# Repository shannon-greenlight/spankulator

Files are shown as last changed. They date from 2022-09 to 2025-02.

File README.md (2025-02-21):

# Spankulator
# The Spankulator has been discontinued due to parts issues

The Spankulator is a WiFi-enabled multi-function Eurorack module. Its main function is to generate a trio of coordinated analog and digital signals which can be used in an endless variety of ways. While each output generates familiar signals, it is the coordination of these signals and the methods of control that make the Spankulator special.

# Spankulator-Hardware, Spankulator-Panel
These repos contain the materials needed to construct the Spankulator main board and the front panel.
The files are for KiCAD 6.0. Go to the Greenlight Kicad repo to get the needed libraries.
The gerber files work with JLCPC and will most likely work with other board manufacturers.
Assembly instructions are in spankulator_assembly.docx.

If starting from a bare circuit board, the BOM for the Spankulator is in bom/Digi-Key/spankulator_full.csv. This file can be directly uploaded to Digi-Key for buying parts.

If using the JLCPCB assembly service, the BOM is split into 3 parts.
- bom/LCSC/spankulator_bom.csv : The parts to be assembled by JLCPCB
- bom/Digi-Key/spankulator_split.csv : The remaining parts to be assembled by user
- bom/Other/other_bom.xlsx : The parts that must be bought from sources other than JLCPCB and Digi-Key

Also, when an assembly service is used, a component position file is required. This file's path is: fab/spankulator_cpl.xlsx

notes: 	The bom and cpl files are auto-generated from the csv BOM files produced by KiCAD. You will need to refresh the data when changes to the schematic that affect the BOM or changes to the board layout occur.
		The data that is the source of the BOM files is generated by the BOM function in KiCAD schematics. Use the bom2grouped_csv.xsl plugin that's supplied with KiCAD. 
		This produces Spankulator.xml, which is used by the Python scripts found in the KiCAD repository. https://github.com/shannon-greenlight/KiCAD
		Once Spankulator.xml is up to date, use the generate_boms.bat batch file to create the BOMs. Edit this file to set the directory locations to match your system.
		The cpl file source is generated by the KiCAD pcb Fabrication Output function. File->Fabrication Outputs->Component Placement. Make sure to select "Separate files for front and back".
		Select ./fab/pos as the output directory. This creates the pos files, the 'top' file being used as the data source for the cpl file that is sent to JLCPCB: fab/spankulator_cpl.xsl
		Make sure to refresh the data and save the file before sending it to JLCPCB.
		
The additional data fields that appear on the schematic help to produce the different BOM files. They must be maintained for these BOMs to come out right.

# Spankulator-Code
This repository contains the elements needed to build code for the Spankulator. 
The code is for the Arduino Nano 33 IoT and is found in the Spankulator folder. Make sure to get the required libraries from the Arduino-Libs repo.

The build files are for Windows. They are simple .bat files but depend on having a working Arduino development system.
Certain variables must be edited to adapt these files to a particular installation. 

Here is a list of the batch files and folders:
 
- make.bat ... compiles the code
- make_n_load.bat ... calls make.bat then uploads the code to the Spankulator
- load_recent.bat ... loads most recent compile
- list_ports.bat ... lists available COM ports
- release.bat ... used to update release number in the code and create release binary zip
- out ... this folder must be created. It holds compile output

# Du Dad
The Du Dad is an addition to the Spankulator that provides these benefits:

- Front Panel USB access
- Power sensing shuts off USB to Arduino when synth power is off
- Reset switch
- USB Power indicator
- Boot Loader / Ext Trig Disabled indicator
- Trig In Latch indicator
- Extremely useful to those who use Terminal Remote mode

The folder structure of the Du Dad is similar to the Spankulator Hardware folder. Currently there is no support for assembly service.

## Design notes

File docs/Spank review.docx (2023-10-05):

I'm the designer of the Spankulator. This is more of a description than a review.

The unit shown is new. Because Patchwerks needs to see some interest in my products before they carry them, I must sell in the consignment section. I'm hoping that people see how cool this module is and that this is a good way to get the ball rolling.

The Spankulator is designed to be a highly versatile coordinated Trigger/CV source.

Signals

Trig Out – Digital signal that consists of pulses of varying width.

Tog Out – Digital signal that toggles at the end of every sequence.

CV Out – Analog signal (+/- 5 volt) that depends on the Function. Usually, it is relative to the pulse width of the Trig Output. This signal is modified using the CV control.

Trigger In – Digital input. Operation is triggered with a 0 to 5 volt transition on this input. This also serves as the External Clock when Ext Clk mode is enabled.

Sig In – Analog signal input. Range: +/- 5 volt

Functions

5 Spank types – Up, Down, Stretch, Toggle and Maytag

LFO with 4 waveforms – Sine, Inv Sine, Ramp Up, Ramp Down

Bounce – A DVM plus a quantizable sample and hold. DC and AC modes

User Mode – For sending sequences of Spanks and/or LFO bursts

WiFi Mode – For configuring WiFi

Settings – For module configuration, factory reset, etc.

There is a lot more to say. I wrote a manual with 30 pages of useful info. You can find it here: https://www.greenfacelabs.com/wp-content/uploads/2023/08/Spankulator-Manual.pdf

If you are interested, please contact me directly using the contact page on my website. I'm constantly upgrading the Spankulator and will probably have some important updates.

And I'm looking for a Keith Emerson to help me make a name for Greenface Labs. If you have a significant following, or are an influencer and would like to check out the Spankulator for FREE please use the contact page to claim one for yourself. https://www.greenfacelabs.com/contact/ US or Canada only please.

Shannon Vance

Greenface Labs

Hood River, Oregon

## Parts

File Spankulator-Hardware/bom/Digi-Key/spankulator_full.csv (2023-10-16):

Reference | Quantity | Value | Digi-Key Part #
A1, | 1 | Nano_33IoT | 1050-ABX00032-ND
C1, C2, C18, C19, | 4 | 10nF | BC2662CT-ND
C3, C4, | 2 | 100uF | 10-ECE-A1CKA101ICT-ND
C5, C6, C7, C9, C12, C13, C17, C20, | 8 | 100nF | 399-9877-1-ND
C8, C10, C14, C21, | 4 | 1uF | 399-9886-1-ND
C11, C15, | 2 | 2.2uF | 478-12960-1-ND
C16, | 1 | 270p | 490-7362-1-ND
D1, D2, D7, D15, D16, D19, D20, | 7 | 1N5711 | 497-2499-1-ND
D3, | 1 | GREEN LED | 732-5008-ND
D4, | 1 | BLUE LED | 732-11401-ND
D5, | 1 | YELLOW LED | 160-1961-ND
D6, D13, | 2 | 1N4148 | 1N4148VSCT-ND
D8, | 1 | 1N5819 | 497-2499-1-ND
D9, | 1 | 1N5819 | 497-2499-1-ND
D14, | 1 | RED LED | 160-1035-ND
J1, J3, J4, J5, J6, | 5 | 3.5mm Jack | WM17366-ND
J2, J7, | 2 | 2x5 Header | S2011EC-05-ND
J9, | 1 | Display Header | SAM1011-04-ND
J11, | 1 | OLED Pins | 732-5317-ND
J12, J13, | 2 | Arduino Socket | S7048-ND
J14, | 1 | Eurorack Power Cable | H3CCS-1618G-ND
KN1, | 1 | Selector Knob | 226-4215-ND
KN2, | 1 | CV Knob | 1722-1314-ND
N2, N3, N4, N5, N6, N7, | 6 | Nut | 36-4687-ND
Q1, | 1 | 2N3904 | 2N3904FS-ND
R1, R5, R6, R11, R15, R22, | 6 | 10K | CF14JT10K0CT-ND
R2, R3, R4, R10, R14, | 5 | 1K | CF14JT1K00CT-ND
R7, R12, R24, R26, R27, R31, | 6 | 100K .1% | A105968CT-ND
R8, | 1 | 100K | 2019-CF1/4CT52R104JCT-ND
R9, R13, | 2 | 43K | CF14JT43K0CT-ND
R17, | 1 | 324K 1% | 324KXBK-ND
R18, | 1 | 68K | CF14JT68K0CT-ND
R19, R20, | 2 | 470 | PPC470W-1CT-ND
R23, R28, | 2 | 300K .1% | RN55E3003BB14-ND
R29, | 1 | 200K .1% | CMF200KHCCT-ND
R30, | 1 | 95.3K 1% | RNF14FTD95K3CT-ND
RV1, | 1 | 1K | PTV09A-4225F-B102-ND
RV2, RV3, | 2 | 20K | 490-2881-ND
SC2, SC4, SC6, SC8, | 4 | Nylon Screw | 36-29331-ND
SC3, SC5, SC7, SC9, | 4 | Mounting Screw | 335-1156-ND
SK1, SK2, SK3, SK5, | 4 | A_08-LC-TT | AE9986-ND
SK4, | 1 | A_14-LC-TT | AE9989-ND
SO2, SO3, SO5, SO7, | 4 | Standoff 12mm | 732-13063-ND
SO4, SO6, | 2 | Standoff 10mm | 732-13055-ND
SO8, SO9, SO10, SO11, SO12, | 5 | LED_Standoff | 732-11607-ND
SW1, | 1 | Adj | 987-1187-ND
SW2, SW3, SW4, SW5, SW6, SW7, SW8, | 7 | Push Button | 450-1643-ND
TP1, TP2, TP3, TP4, | 4 | TestPoint | 36-5006-ND
U1, U3, | 2 | TL072CP | 296-1775-5-ND
U2, | 1 | CD4013BE | 296-2033-5-ND
U4, | 1 | MC78L05_TO92 | 296-27135-1-ND
U5, | 1 | LP2950-3.3_TO92 | 296-26120-ND
U6, | 1 | MAX7480 | MAX7480EPA+-ND
U7, | 1 | MB85RC256 | 865-1261-1-ND
U8, | 1 | MCP6002-E/P | MCP6002-E/P-ND

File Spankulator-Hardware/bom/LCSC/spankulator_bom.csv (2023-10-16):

Designator | Comment | Footprint | JLCPCBPart#
C1, C2, C18, C19, | 10nF | Capacitor_THT:C_Disc_D4.3mm_W1.9mm_P5.00mm | C263180
C3, C4, | 100uF | Capacitor_THT:CP_Radial_D6.3mm_P2.50mm | C445356
C5, C6, C7, C9, C12, C13, C17, C20, | 100nF | Capacitor_THT:C_Disc_D4.3mm_W1.9mm_P5.00mm | C400087
C8, C10, C14, C21, | 1uF | Capacitor_THT:C_Disc_D4.3mm_W1.9mm_P5.00mm | C94708
C11, C15, | 2.2uF | sputterizer:CP_Radial_Tantal_D4.5mm_P5.00mm_Min | C50520
C16, | 270p | Capacitor_THT:C_Disc_D5.0mm_W2.5mm_P5.00mm | C263193
D1, D2, D7, D15, D16, D19, D20, | 1N5711 | Diode_THT:D_DO-35_SOD27_P7.62mm_Horizontal | C283247
D6, D13, | 1N4148 | Diode_THT:D_DO-35_SOD27_P7.62mm_Horizontal | C84412
D8, | 1N5819 | Diode_THT:D_DO-41_SOD81_P2.54mm_Vertical_AnodeUp | C110032
D9, | 1N5819 | Diode_THT:D_DO-41_SOD81_P2.54mm_Vertical_KathodeUp | C110032
Q1, | 2N3904 | Package_TO_SOT_THT:TO-92-3_Formed_Leads | C258185
R1, R5, R6, R11, R15, R22, | 10K | Resistor_THT:R_Axial_DIN0207_L6.3mm_D2.5mm_P10.16mm_Horizontal | C120103
R2, R3, R4, R10, R14, | 1K | Resistor_THT:R_Axial_DIN0207_L6.3mm_D2.5mm_P10.16mm_Horizontal | C66649
R7, R12, R24, R26, R27, R31, | 100K .1% | Resistor_THT:R_Axial_DIN0207_L6.3mm_D2.5mm_P10.16mm_Horizontal | C410694
R8, | 100K | Resistor_THT:R_Axial_DIN0207_L6.3mm_D2.5mm_P10.16mm_Horizontal | C120103
R9, R13, | 43K | Resistor_THT:R_Axial_DIN0207_L6.3mm_D2.5mm_P10.16mm_Horizontal | C433719
R17, | 324K 1% | Resistor_THT:R_Axial_DIN0207_L6.3mm_D2.5mm_P10.16mm_Horizontal | C1369146
R18, | 68K | Resistor_THT:R_Axial_DIN0207_L6.3mm_D2.5mm_P10.16mm_Horizontal | C70783
R19, R20, | 470 | Resistor_THT:R_Axial_DIN0207_L6.3mm_D2.5mm_P10.16mm_Horizontal | C129899
R23, R28, | 300K .1% | Resistor_THT:R_Axial_DIN0207_L6.3mm_D2.5mm_P10.16mm_Horizontal | C173001
R29, | 200K .1% | Resistor_THT:R_Axial_DIN0207_L6.3mm_D2.5mm_P10.16mm_Horizontal | C172982
R30, | 95.3K 1% | Resistor_THT:R_Axial_DIN0207_L6.3mm_D2.5mm_P10.16mm_Horizontal | C172602
SK1, SK2, SK3, SK5, | A_08-LC-TT | Package_DIP:DIP-8_W7.62mm_Socket | none
SK4, | A_14-LC-TT | digikey-footprints:Socket_DIP-14_7.62mm_Conn | none
SW2, SW3, SW4, SW5, SW6, SW7, SW8, | Push Button | Button_Switch_THT:SW_PUSH_6mm | C266209
U1, U3, | TL072CP | Package_DIP:DIP-8_W7.62mm_Socket | C72124
U2, | CD4013BE | Package_DIP:DIP-14_W7.62mm_Socket | C132508
U4, | MC78L05_TO92 | Package_TO_SOT_THT:TO-92_Inline_Wide | C156437
U5, | LP2950-3.3_TO92 | Package_TO_SOT_THT:TO-92-3_Formed_Leads | C133551
U6, | MAX7480 | Package_DIP:DIP-8_W7.62mm_Socket_LongPads | C72124
U7, | MB85RC256 | Package_SO:SOIC-8_3.9x4.9mm_P1.27mm | C47538
U8, | MCP6002-E/P | Package_DIP:DIP-8_W7.62mm_Socket | C72124

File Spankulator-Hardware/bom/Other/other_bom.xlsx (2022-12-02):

Reference | Quantity | Value | URL
A1 | 1 | Nano_33IoT | https://www.amazon.com/Arduino-Nano-33-IoT/dp/B07VW9TSKD/
M2 | 1 | OLED | https://www.amazon.com/gp/product/B072Q2X2LL/
RV2 | 1 | 20K | https://www.amazon.com/dp/B015RK03LI?psc=1&ref=ppx_yo2ov_dt_b_product_details

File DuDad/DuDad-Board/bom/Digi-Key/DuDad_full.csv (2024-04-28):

Reference | Quantity | Value | Digi-Key Part #
D1, | 1 | RED LED | 732-5005-ND
D2, | 1 | GREEN LED | 732-5008-ND
D3, | 1 | YELLOW LED | 732-5010-ND
J1, | 1 | EXP | S2011EC-05-ND
J2, | 1 | USB_B_Micro | 2073-USB3131-30-0230-ACT-ND
J3, | 1 | USB_A | UE27AE54100-ND
Q1, Q2, Q4, | 3 | 2N3906 | 2N3906TFCT-ND
Q3, | 1 | 2N7000 | 2N7000FS-ND
R1, R4, | 2 | 620 | CF14JT620RCT-ND
R2, R5, R7, R8, | 4 | 30K | CF14JT30K0CT-ND
R3, | 1 | 1K | CF14JT1K00CT-ND
R6, R9, | 2 | 10K | CF14JT10K0CT-ND
SW1, | 1 | Reset | 450-1653-ND

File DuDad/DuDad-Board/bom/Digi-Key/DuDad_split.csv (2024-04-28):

Reference | Quantity | Value | Digi-Key Part #
D1, | 1 | RED LED | 732-5005-ND
D2, | 1 | GREEN LED | 732-5008-ND
D3, | 1 | YELLOW LED | 732-5010-ND
J2, | 1 | USB_B_Micro | 2073-USB3131-30-0230-ACT-ND
SW1, | 1 | Reset | 450-1653-ND

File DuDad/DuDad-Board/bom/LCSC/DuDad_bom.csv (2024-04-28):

Designator | Comment | Footprint | JLCPCBPart#
J1, | EXP | Connector_PinHeader_2.54mm:PinHeader_2x05_P2.54mm_Vertical | C225520
J3, | USB_A | sputterizer:USB_A_Amphenol_UE27AE54100_Vertical | C386737
Q1, Q2, Q4, | 2N3906 | Package_TO_SOT_THT:TO-92_Inline_Wide | C9809
Q3, | 2N7000 | Package_TO_SOT_THT:TO-92_Inline_Wide | C232838
R1, R4, | 620 | Resistor_THT:R_Axial_DIN0207_L6.3mm_D2.5mm_P10.16mm_Horizontal | C120050
R2, R5, R7, R8, | 30K | Resistor_THT:R_Axial_DIN0207_L6.3mm_D2.5mm_P10.16mm_Horizontal | C176499
R3, | 1K | Resistor_THT:R_Axial_DIN0207_L6.3mm_D2.5mm_P10.16mm_Horizontal | C120055
R6, R9, | 10K | Resistor_THT:R_Axial_DIN0207_L6.3mm_D2.5mm_P10.16mm_Horizontal | C433778

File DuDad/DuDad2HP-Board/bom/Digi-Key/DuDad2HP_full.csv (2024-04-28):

Reference | Quantity | Value | Digi-Key Part #
D1, | 1 | RED LED | 732-5005-ND
D2, | 1 | GREEN LED | 732-5008-ND
D3, | 1 | YELLOW LED | 732-5010-ND
J1, | 1 | EXP | S2011EC-05-ND
J2, | 1 | USB_B_Micro | 2073-USB3131-30-0230-ACT-ND
J3, | 1 | USB_A | UE27AE54100-ND
Q1, Q2, Q4, | 3 | MMBT3906 | MMBT3906LT1GOSCT-ND
Q3, | 1 | 2N7002 | 2N7002LT1GOSCT-ND
R1, R4, | 2 | 620 | RMCF0805FT620RCT-ND
R2, R5, R7, R8, | 4 | 30K | RMCF0805FT30K0CT-ND
R3, | 1 | 1K | 311-1.00KCRCT-ND
R6, R9, | 2 | 10K | RMCF0805FT10K0CT-ND
SW1, | 1 | Reset | 450-1940-ND

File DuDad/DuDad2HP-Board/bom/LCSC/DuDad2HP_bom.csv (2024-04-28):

Designator | Comment | Footprint | JLCPCBPart#
J1, | EXP | Connector_PinHeader_2.54mm:PinHeader_2x05_P2.54mm_Vertical_SMD | C178296
J3, | USB_A | sputterizer:USB_A_Amphenol_UE27AE54100_Vertical | C386737
Q1, Q2, Q4, | MMBT3906 | Package_TO_SOT_SMD:SOT-23 | C266589
Q3, | 2N7002 | Package_TO_SOT_SMD:SOT-23 | C8545
R1, R4, | 620 | Resistor_SMD:R_0805_2012Metric_Pad1.20x1.40mm_HandSolder | C17782
R2, R5, R7, R8, | 30K | Resistor_SMD:R_0805_2012Metric_Pad1.20x1.40mm_HandSolder | C17621
R3, | 1K | Resistor_SMD:R_0805_2012Metric_Pad1.20x1.40mm_HandSolder | C17513
R6, R9, | 10K | Resistor_SMD:R_0805_2012Metric_Pad1.20x1.40mm_HandSolder | C17414

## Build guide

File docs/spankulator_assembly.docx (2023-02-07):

# Spankulator Assembly Instructions

The Spankulator uses components on both sides of the board. Pre-populated boards have most of the top side components installed. The order of assembly is designed to add components like the push buttons near the end of the process so they will not risk being damaged by the hot iron. However, pre-populated boards may have the buttons or other vulnerable components installed. In this case, extra caution is required.

These instructions work for bare boards and also for pre-populated boards from JLCPCB. In the latter case, you only will need to install components that haven’t already been installed. The list of these components can be found in the file: Spankulator-Hardware\bom\Digi-Key\ spankulator_split.csv

Because of the density of the circuitry, a conical .8mm tip soldering iron is suggested. It is strongly recommended that you read the Test Instructions before attempting assembly.

Difficulty: beginner. Not recommended for first two builds.

1. Load the Spankulator program onto the Arduino via micro-USB cable using the updater batch file. The latest updater package is found on the Spankulator page of the website. Other versions can be found in the Git repository.
2. Install 4 12mm stand-offs to the front panel using screws. Set this aside for later.
3. Install U7
4. Install all resistors, capacitors, diodes, transistors, test points, and sockets to the top side of the board.
5. Install ICs into sockets (not Arduino)
6. Install J9 display header to top side.
7. Install 2 10mm display stand-offs with nuts.
8. Solder header to Display board. Set this aside for later.
  a. Trim pins on top of display to insure proper fit onto the front panel.
  b. Note: the display is very fragile. Avoid unnecessary handling.
9. Install back side components. (Connectors, Arduino sockets, and trimpots)
10. Install display. Use wooden, round toothpicks to align display on standoffs. Insert toothpick from top and trim flush with display surface.
11. Loosely place the rest of the components (these should all be the ones that go through holes in the front panel) and attach front panel with the 4 nuts.
12. This should properly align all the front-panel components. Solder them in place.
13. Install Arduino on the back side of the board.
14. Attach knobs
15. That’s all! You’re ready to test.

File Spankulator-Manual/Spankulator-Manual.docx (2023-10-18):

# The Spankulator

User Manual

Greenface Labs -- 2023

# Quick Start

The Spankulator can be used in an endless variety of ways, but here is a great way to start exploring. These instructions are for use with a Moog Mother-32 but can be easily adapted to most modular synthesizers. Note - you may need to set the encoder type in Settings first.

#### Mother-32 Set-up

- VCA Mode – EG (use the envelope generator)
- VCO Mod Amount – Zero
- VCF Mode – Low Pass
- VCF Mod Source – EG
- VCF Mod Amount – 0%
- Cutoff – 200Hz
- Resonance – 50%
- Attack – 5%
- Decay 10%
- Sustain – Off
- Frequency – 50%
- Pulse Width – 50%
- VCO Wave - Pulse
- Octave – 4
- Note – 8

#### Spankulator Set-Up

- Fxn – Down (use default parameters as shown in images below)
- Start Pulse Len – 100
- End Pulse Len – 10
- Num Pulses – 10
- Randomness – 0
- Initial Delay 100
- Repeat – On
- CV Scale – 50%

Connect the Spankulator Trig Out to the M-32 Gate Input, Tog Out to the M-32 VCF Cutoff Input and CV Out to the M-32 VCO Lin Input. Press Trigger on the Spankulator and you should hear a sound much like that found here (https://www.greenfacelabs.com/posts/spankulator-quick-start-example/).

# Overview

The Spankulator is a WiFi-enabled multi-function Eurorack module. Its main function is to generate a trio of coordinated analog and digital signals which can be used in an endless variety of ways. While each output generates familiar signals, it is the coordination of these signals and the methods of control that make the Spankulator special.

## Signals

- Trig Out – Digital signal that consists of pulses of varying width.
- Tog Out – Digital signal that toggles at the end of every sequence.
- CV Out – Analog signal (+/- 5 volt) that depends on the Function. Usually, it is relative to the pulse width of the Trig Output. This signal is modified using the CV controls.
- Trigger In – Digital input. Operation is triggered with a 0 to 5 volt transition on this input. This also serves as the External Clock when Ext Clk mode is enabled.
- Sig In – Analog signal input. Range: +/- 5 volt

## Functions

- 5 Spank types – Up, Down, Stretch, Toggle and Maytag
- LFO with 4 waveforms – Sine, Inv Sine, Ramp Up, Ramp Down
- Bounce – A DVM plus a quantizable sample and hold. DC and optional AC modes
- User Mode – For sending sequences of Spanks and/or LFO bursts
- WiFi Mode – For configuring WiFi connection
- Settings – For module configuration, factory reset, etc.

## Features

- 128x64 graphic display enhances usability
- Web and Terminal interfaces provide rich user experiences with the addition of computer resources like a keyboard, mouse, display and scripting.
- All settings are stored in Flash memory so that they are retained when power is off
- Selectable Single Shot or Repeat mode
- CV scale, offset and value are independently controllable via CV pot and Sig In
- CV Out can be Quantized
- Randomness can be added to most function ranging from 0 to 99%
- External Clock mode
- Inputs and Outputs are protected against damage during typical use

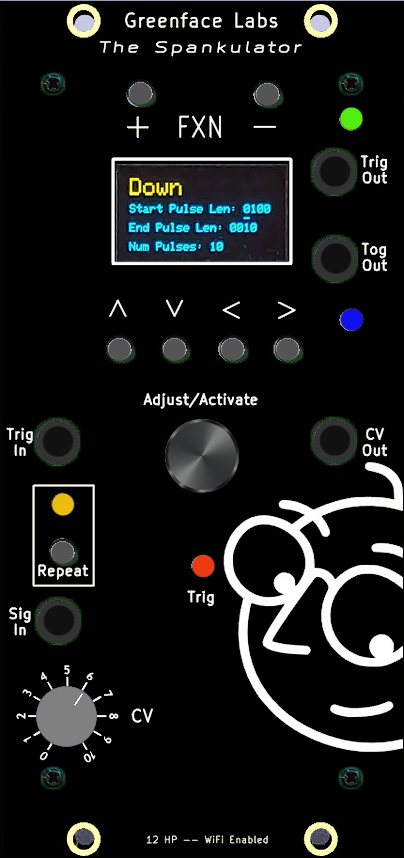
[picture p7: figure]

Figure 1 - Front Panel

## Open-Source Project

The Spankulator is an Open-Source project that has an Arduino 33 IoT at its core. The code is written in C++ and makes use of several public domain code libraries for managing the various purchased hardware components such as the display and the FRAM non-volatile memory.

Because it is Open Source, in addition to being used by musicians and sound designers to create new and amazing sounds, the Spankulator can be used by students and entrepreneurs to create new, amazing modules. And, of course, the open-source community will generally improve the product as times goes along. Links to the design repositories can be found on the Spankulator web page.

# Operation

## General Operation

(Please see the Terminal and Web Interface sections for more details)

- The Function is selected using the + and – buttons.
  - Terminal uses the + and – keys.
  - Web Interface has dedicated Function buttons.
  - Each function has one or more parameters.
- Parameters are adjusted using the arrow keys and the Adjust knob.
  - Parameters are selected using the up and down arrows.
  - Digit to be adjusted is selected by using the right and left arrows.
  - When entering strings, holding the right or left arrow down for 2 seconds inserts (right) or deletes (left) a character.
  - Use the Adjust knob to increment and decrement the selected digit.
  - Parameter values may be directly entered using the Terminal or Web Interface.
- Operation of each function is triggered by a variety of methods.
  - Pressing the Adjust button.
  - Receiving a low to high transition on the Trig In jack.
  - Terminal uses the ! key to trigger.
  - Web Interface has a dedicated Trigger button.
- Trigger may be single-shot or repetitive.
  - Press the Repeat button to toggle the Repeat mode.
  - Terminal uses the * key to toggle Repeat mode.
  - Web Interface has a dedicated Repeat button.
- CV Out amplitude, offset and value can be adjusted by a variety of methods.
  - Use the CV potentiometer or Sig In. Select adjust functions in Settings.
  - Terminal uses the S, O and c keys plus up to four digits. (Use the z key to refresh the screen after setting this parameter to see the result.)
  - Web Interface has a dedicated Slider control for each function.
- CV Quantization can be selected in Settings by the following methods.
  - Terminal uses q0 to turn Quantization OFF.
  - Terminal uses q1 to turn Quantization ON.

## Note on CV Input/Output

The Spankulator is designed to operate on a +/-5V range. There are usage scenarios that require a different range (0-8V for example). For these scenarios, it is recommended that an external biasing module be used. The 4MS SISM module is recommended, but there are many others that would work.

## Trigger

The Spankulator is controlled by the user issuing Commands. Commands are initiated by pressing the front panel buttons or by using the Web or Terminal interfaces. Regardless of the source of the command, it will be called either a command or a keypress in this document.

The various functions that the Spankulator performs are called “Spanks” and will be referred to as such in this document.

All the Spankulator’s functions are activated by a trigger. Triggers can come from various sources:

- Pushing the Trigger (Adjust) knob.
- Receiving a 0 to 5V transition on the Trig In jack.
- Receiving a Trigger command from either the Web or Terminal interface

When a Trigger is received, the Spankulator will execute a Spank that sends pulses at the Trig Out jack and varying voltage levels at the CV Out jack. When the Spank ends, the Tog Out jack will switch polarity from one to zero or vice versa.

## Repeat Mode

If Repeat is set to OFF, the Spankulator will remain in whatever condition it was in when the Spank ended until it receives another Trigger.

If Repeat is set to ON, the Spank will continuously repeat.

In either case, receipt of another Trigger or Command will interrupt the Spank, stopping execution until a new Trigger is received.

The Trigger Indicator will be activated when a trigger is received and will be turned off when the trigger ends. The Trigger Indicator is a Red LED on the front panel and is a widget in the Web Interface. It is textually indicated on the Status line in Terminal mode.

## CV Out

The CV Out signal ranges from -5V to +5V. The range can be adjusted from 0 to 100% by using the CV controls (CV Pot or Sig In). Use Settings to select Scale as the Adjust Function.

The CV Out signal can be offset by -5V to +5V. The offset can be adjusted using the CV controls. Use Settings to select Offset as the Adjust Function.

When the Trigger isn’t active, the CV Out Value can be directly set using the CV controls.

Use Settings to select Value as the Adjust Function.

Web mode has a dedicated slider control for each CV parameter, and Terminal mode uses the S, O and c keys. See the table of remote commands for more details.

## Sig In

The Signal In jack has a range of -5V to +5V. It is used by the CV Controls and the Bounce function.

For the Bounce function, Sig In is split into two parts, one AC coupled, and the other DC coupled. These signals are then scaled and biased to the 0 to 3.3V signal that the Arduino requires. More details about the Bounce function can be found later in this document.

## Screen Saver

In order to maximize display life, the display will turn off after a set time. The default time is 15 minutes. The time can be set in the Settings function with a range of 1 to 9999 minutes.

Press any button or push the Trigger knob or send a ‘z’ via remote to bring the display back.

## Reset on Power On

Holding down the + button when powering up will force a full reset to factory defaults. Unlike a reset done in Settings, this reset includes the WiFi parameters.

# Function Details

The Spankulator has ten functions. These are listed below with their associated command index. Details for each function follow.

1. Up
2. Down
3. Stretch
4. Toggle
5. Maytag
6. LFO
7. User
8. Bounce
9. Web
10. Settings

## Up

Up Spanks send a sequence of pulses that increase in width to Trig Out.

The voltage level at CV Out is proportional to the current pulse width plus or minus a value that is calculated from the Randomness parameter. The voltage will be at the minimum when the Spank starts and will increase to the maximum when the Spank completes. This range and the mid-point can be adjusted by using the CV controls.

Parameter | Min | Max | Default
End Pulse Len | 10 | 9999 | 100
Start Pulse Len | 10 | 9999 | 10
Num Pulses | 2 | 99 | 10
Randomness | 0 | 99 | 0
Initial Delay | 0 | 9999 | 100

The figure below illustrates an Up Spank with the default settings. The yellow trace is Trig Out and the purple trace is CV Out.

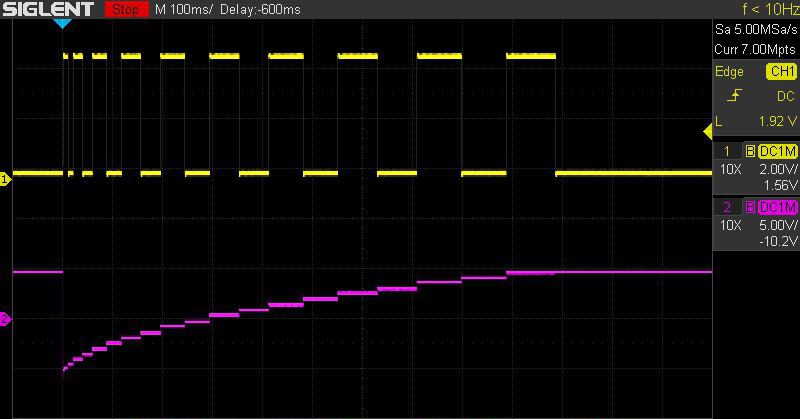
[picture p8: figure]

Figure 2 - Default Up Spank

## Down

Down Spanks send a sequence of pulses that decrease in width to Trig Out.

The voltage level at CV Out is proportional to the current pulse width plus or minus a value that is calculated from the Randomness parameter. The voltage will be at the maximum when the Spank starts and will decrease to the minimum when the Spank completes. This range and the mid-point can be adjusted by using the CV controls.

Parameter | Min | Max | Default
End Pulse Len | 10 | 9999 | 10
Start Pulse Len | 10 | 9999 | 100
Num Pulses | 2 | 99 | 10
Randomness | 0 | 99 | 0
Initial Delay | 0 | 9999 | 100

The figure below illustrates a Down Spank with the default settings. The yellow trace is Trig Out and the purple trace is CV Out.

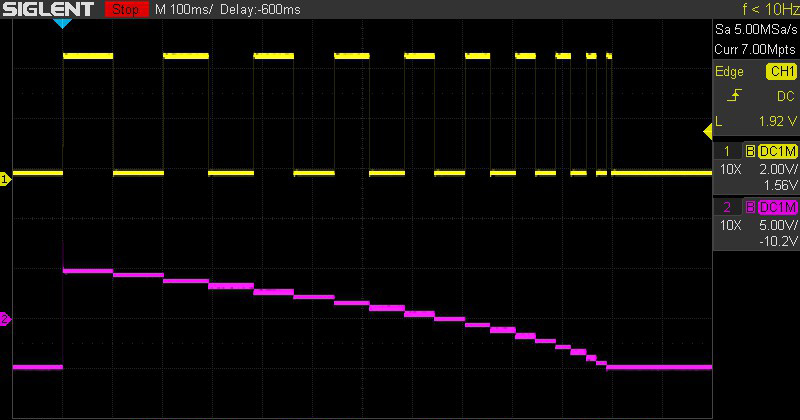
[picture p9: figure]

Figure 3 - Default Down Spank

## Stretch

Stretch Spanks send a sequence of pulses that are the same width to Trig Out. Each pulse is preceded by a delay which is set by the user.

The voltage level at CV Out is set by the user. Level 1 sets the voltage during the pulse and Level 2 sets the voltage during the delay.

Parameter | Min | Max | Default
Pulse Length | 10 | 9999 | 10
Delay | 10 | 9999 | 100
Num Pulses | 2 | 99 | 1
Level 1 | 0 | 1023 | 1023
Level 2 | 0 | 1023 | 512

The figure below illustrates a Stretch Spank with the default settings. The yellow trace is Trig Out and the purple trace is CV Out.

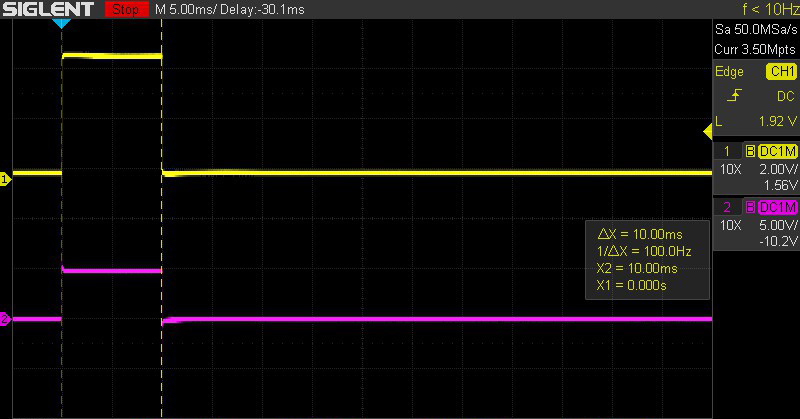
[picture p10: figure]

Figure 4 - Default Stretch Spank

Notes: CV Output levels can be calculated using this formula: n = 102.3*V +512 rounded down to the nearest integer. Where n is the value to enter in Level 1 or 2 and V is the desired output voltage. V ranges from -5V to +5V.

## Toggle

Toggle Spanks send a HIGH, LOW or the opposite of what is currently there to Trig Out.

The voltage level at CV Out is set by the user. Hi Level sets the voltage when the output goes HIGH and Lo Level sets the voltage when low.

Parameter | Min | Max | Default
Delay | 1 | 9999 | 100
Hi Level | 0 | 1023 | 1023
Lo Level | 0 | 1023 | 0
State | LO | HI | Toggle

The figure below illustrates a Toggle Spank with the default settings. The yellow trace is Trig Out and the purple trace is CV Out.

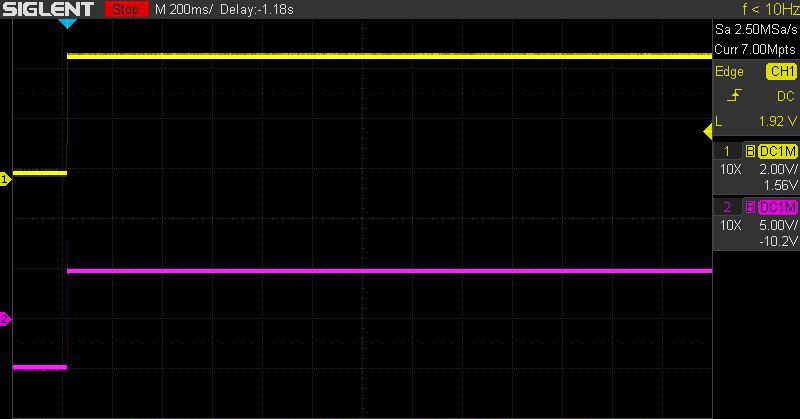
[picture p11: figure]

Figure 5 - Default Toggle Spank

Notes: Toggle mode is useful for setting the output to a known state. Trig Out can be set LO, HIGH or Toggled to the opposite of what it currently is. The levels at CV Out can be set in a similar fashion to Stretch Spanks.

## Maytag

Maytag Spanks send a sequence of pulses of random width to Trig Out. The timing between pulses is determined by Pulse Len. The pulses are sent after the Initial Delay.

The voltage level at CV Out is proportional to the current pulse width plus or minus a value that is calculated from the Randomness parameter. The range and the mid-point can be adjusted by using the CV controls.

Parameter | Min | Max | Default
Pulse Len | 10 | 9999 | 100
Initial Delay | 0 | 9999 | 500
Num Pulses | 2 | 99 | 20

The figure below illustrates a Maytag Spank with the default settings. The yellow trace is Trig Out and the purple trace is CV Out.

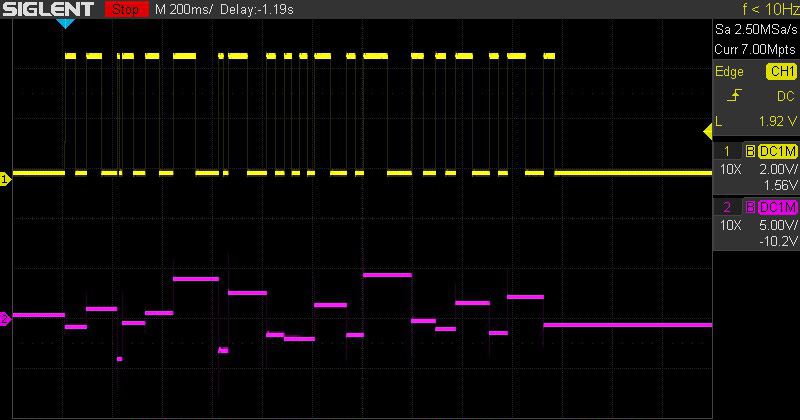
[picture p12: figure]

Figure 6 - Default Maytag Spank

## LFO

LFO Spanks send a Sine wave, an Inverse Sine wave (cosine), a Ramp-Up or a Ramp-Down wave to CV Out. This signal is modified by the Randomness parameter. Each LFO Spank also sends a pulse to Trig Out where the width is equal to the length of the LFO period.

The voltage level at CV Out is 10V peak to peak. The Period is in milliseconds.

Parameter | Min | Max | Default
Period | 2 | 9999 | 10
Waveform | N/A | N/A | SINE
Randomness | 0 | 99 | 0

The figure below illustrates an LFO Spank with the default settings. The yellow trace is Trig Out and the purple trace is CV Out.

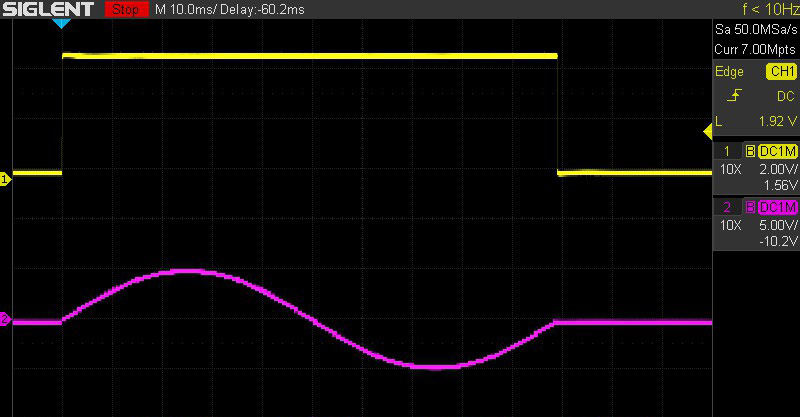
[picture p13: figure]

Figure 7 - Default LFO Spank

The LFO function displays the waveform when CV adjustments are made. Press any key to return to the parameter display. The Web interface shows the waveform continuously. An example of this is shown in the figure below.

Figure 8

Notes:

When in Repeat mode, the waveform will be interrupted by the system in its basic loop. This interruption can be minimized by disabling WiFi in the Settings function.

## User

The User function sends a sequence of Spanks. The User sequence is entered using the right and left arrow keys to select the sequence element and the Adjust knob to enter the Spank at the selected element. Sequence elements are deleted by choosing the blank Spank.

User Spanks

U – Up

D – Down

S – Stretch

T – Toggle

M – Maytag

L - LFO

Entering a Spank copies the main Spank parameters into the User Spank. For example, entering a ‘U’ will copy the parameters from the Up Spank into the User mode parameters at the position the U was entered. Once entered, these parameters can be adjusted. Each User Spank is a separate entity and can be edited without affecting other User Spanks or the Spank that was the initial source of the parameter data.

It is important to note that changing an element of the User sequence will overwrite all the data at the selected element with the data from the newly entered Spank.

Use the down arrow to edit an element’s parameters. When in edit mode, the sequence highlight character will change from an underscore (_) to a caret (^). The underscore will be used to highlight the edited parameter. Use the arrow keys to edit the various parameters and to return to editing the sequence.

The figure below illustrates a User sequence of DUSTM using default settings for all Spanks in the sequence. The yellow trace is Trig Out and the purple trace is CV Out.

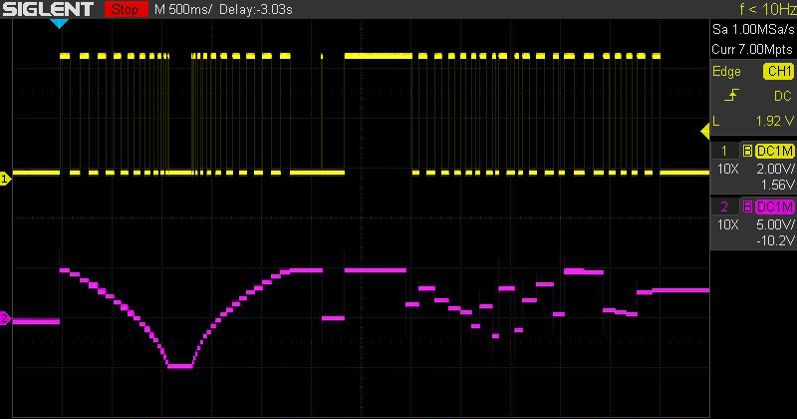
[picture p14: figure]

Figure 9 - Example User Sequence

## Bounce

The Bounce function essentially is a Sample & Hold with extended features. Bounce operates in four modes: DC, DC Quantized, AC and AC Quantized. It measures the voltage at Sig In when a Trigger occurs and then “bounces” that voltage to CV Out. It also generates a 732Hz PWM signal at Trig Out with the duty-cycle proportional to the measurement.

When used in AC mode, Bounce acts as an Envelope Follower.

Mode | 4% Duty Cycle | 96% Duty Cycle
DC | -4.6V | +4.6V
AC | 0V | 10V pk-pk
DC Quantized | -4.6V | +4.6V
AC Quantized | 0V | 10V pk-pk

The basic accuracy of the measurement is 1%

AC is measured as True RMS. For a Sine wave this is (Vpk)/(2*√2) (Freq: 200Hz – 2000Hz)

Note that the Bounce function operates independently of the Quantize parameter in Settings.

Also note that the AC functions are optional and need the switched cap filter chip to be installed. Please contact the factory if you want these functions.

## WiFi

The Spankulator is equipped with a 2.4GHz WiFi interface. When connected to your network, you can control the Spankulator using the Web Interface (http://www.greenfacelabs.com/spankCP) (see example screen below).

WiFi can be disabled in the Settings function. Make sure it is enabled before proceeding in the connection process.

#### Connecting to WiFi

1. Enter WiFi function and press Trigger to scan for networks.
2. Use the up and down arrow keys to select your network. Press Trigger.
3. Use the right and left arrow keys with the Adjust control to select each character of your password. Press Trigger when your password is entered. Note: It is much easier in Terminal mode. Type your password preceded by $, then press Enter.

The Spankulator will try to connect using the password that you entered. If successful, the screen will display the connection data. This includes the connection status, the IP it can be found at and the signal strength. The signal strength will also be displayed in the upper right corner of the display as 1-4 bars. The signal strength display is shown in most functions.

If the connection fails, the Spankulator will give its best explanation of why it failed.

The Spankulator remembers its connection and will reestablish it if the power is recycled.

Visiting the WiFi function again while connected will display the connection data. Press Trigger to re-enter the scan for networks screen.

Re-scanning networks will reset the password, so it must be entered again to connect.

#### Using WiFi

The Spankulator’s Web Interface was designed to resemble the physical front panel. However, because the Web Interface enjoys the added functionality a computer brings, it has significant differences. Please refer to the following image.

Instead of Fxn+ and Fxn- buttons, there is a dedicated button for each function.

While you can still adjust parameters a digit at a time, you can now enter parameters from the keyboard by first clicking on the parameter then using the dedicated entry field.

Adjusting parameters digit by digit is possible by using the right and left arrows to select the digit and using the Inc and Dec buttons to increment and decrement the digit.

Clicking on the Trig Out and Tog Out indicators changes the state of those outputs.

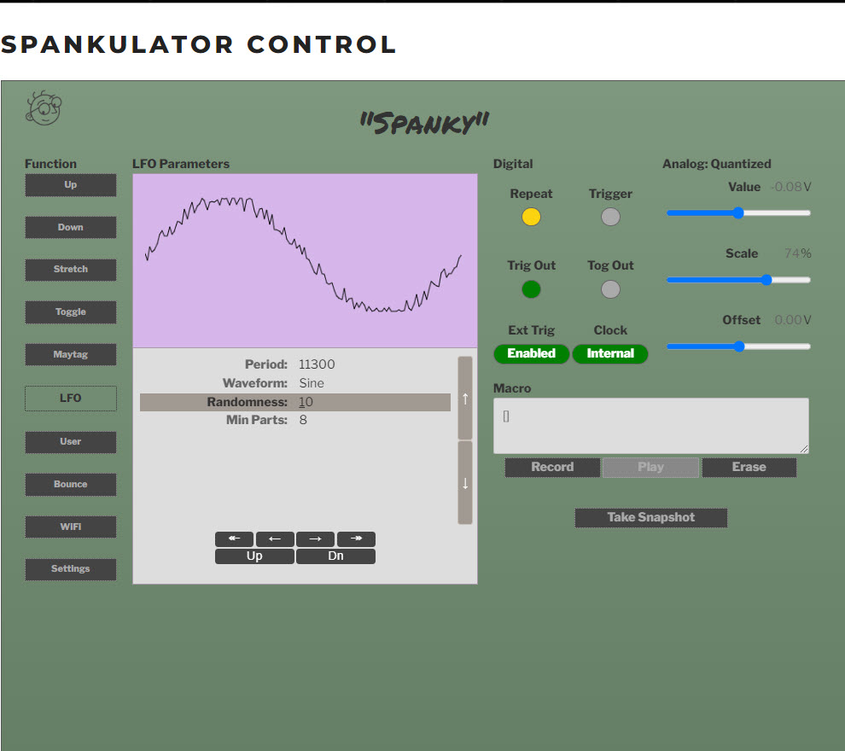
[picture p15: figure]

Figure 10 – Web Interface Example

## USB Direct Mode

USB Direct Mode allows you to control the Spankulator via USB using a desktop app that emulates the Web Interface. It also has the added benefit of being able to display trigger events as they occur rather than having to request them as in the web app. USB Direct Mode is enabled on the Spankulator in two ways:

- In Settings
  - USB Direct Disabled
  - USB Direct Enabled
- Terminal Command
  - U0 - USB Direct Off
  - U1 - USB Direct On

Get the desktop app from the website (https://www.greenfacelabs.com/bonkulator/). Unzip the x64 folder into a convenient location and run the exe file contained in that folder. You should see a screen like the following:

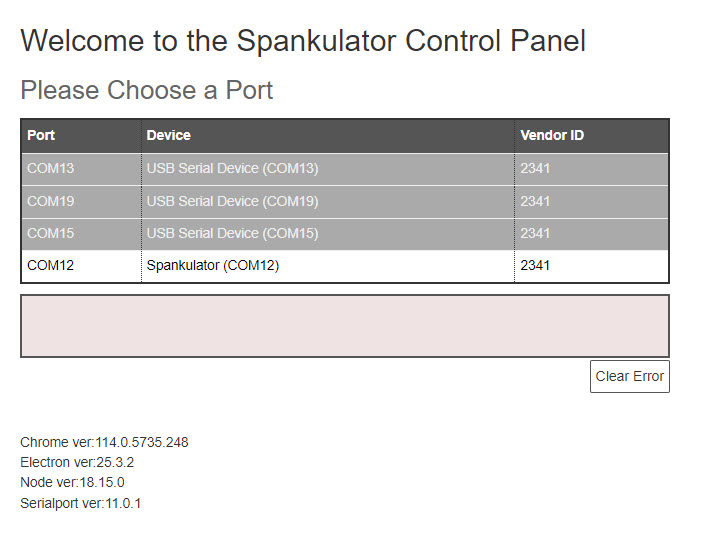
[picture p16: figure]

The devices that show as Spankulator with a vendor id of 2341 should be your Spankulators. Choose a Spankulator by clicking on the path entry of the table.

It will bring up something like the following screen. Use it like you’d use the web app.

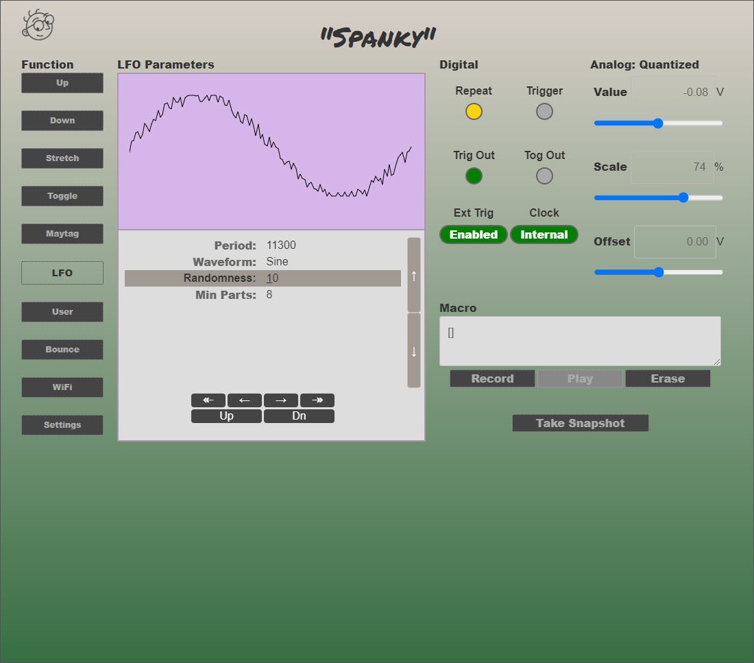
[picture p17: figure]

Figure 11 – Desktop App Example

## Terminal Mode

Terminal mode is accessed via the MicroUSB connector on the Arduino that is on the bottom of the Spankulator. It is always available and cannot be turned on or off.

Use a terminal emulation program like PuTTY that has VT-100 mode. The Spankulator is set to run at 115200 baud but will adapt to the PuTTY settings.

Please refer to the table of commands that follows this section.

#### Terminal Example Screen

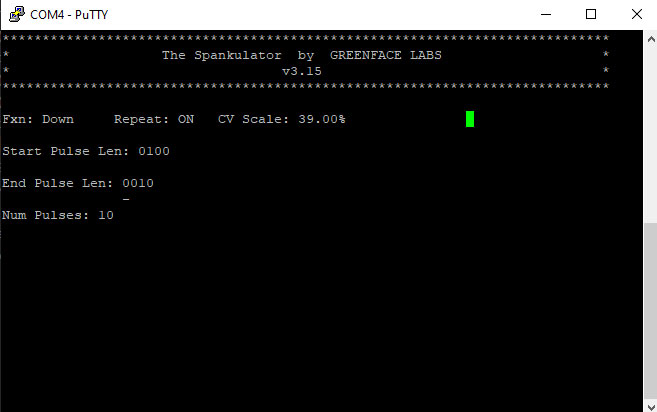
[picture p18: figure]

Figure 12 - Terminal Interface Screen

Important! Only connect USB to a powered-up system. Otherwise, the 5V power from the USB will try to power the entire rack. And that’s not really good. So, please disconnect the USB cable before you turn off the power or use the Du Dad.

#### Spankulator Remote Commands

Command | Front Panel | Terminal | Web
Go to Settings | | * | Click Settings
Next Function | + | + | Next
Previous Function | - | - | Prev
Previous Parameter | ^ | [A | ^
Next Parameter | v | [B | v
Next Digit | > | [C | >
Previous Digit | < | [D | <
Increment Digit | Adjust clockwise | u | Inc
Decrement Digit | Counter-clockwise | d | Dec
Toggle Repeat | Repeat | & | Repeat
Toggle Trigger | Push Adjust | ! | Trigger
Disable Displays | | Z
Restore Displays | | z | Refresh Browser
Insert blank char | Hold > | i
Delete char | Hold < | Backspace
Go To Function | | fx | Click Fxn Name
Select Parameter | | px | Click on Param
Select Digit# | Use Arrow Keys | :xx | Use Arrow Keys
Enter Parameter | | xxxx | Use Param Input
CV Offset | Use Adj | Oxxxx | Use Offset slider
CV Scale | Use Adj | Sxxxx | Use Scale slider
CV Out (scaled) | | Cxxxx
CV Out (unscaled) | | cxxxx | Use Value Slider
Select User Seq | Use Arrow Keys | s | Use Arrow Keys
Display Off | | J0
Display On | | J1
Trigger Off | | t0
Trigger On | | t1
Trigger Toggle | | t2
Tog Out Off | | T0
Tog Out On | | T1
Tog Out Toggle | | T2
Quantization Off | | q0
Quantization On | | q1
Trig Out Off | | G0
Trig Out On | | G1
Trig Out Toggle | | G2
Repeat Off | | r0
Repeat On | | r1
Repeat Toggle | | r2
Turn Off Display | | J0
Turn On Display | | J1
Use Internal Clock | | K0
Use External Clock | | K1
Toggle Ext Clock | | K2
Disable Triggers | | D0
Enable Triggers | | D1
Toggle Trig Enable | | D2
Reset Triggers | | D3
Enable Ext Trigger | | E0
Disable Ext Trigger | | E1
Toggle Ext Trigger | | E2
CV Pot : Off | | P0
CV Pot : Scale | | P1
CV Pot : Offset | | P2
CV Pot : Value | | P3
Sig In : Off | | V0
Sig In : Scale | | V1
Sig In : Offset | | V2
Sig In : Value | | V3
For String Entry | | $xxxxxxx

Notes:

- Commands with yellow background require the user to press Enter when using a terminal. Not Required when sending via Web (REST interface).
- CV Scale– Range: 0-4095 => 0 – 100%
- CV Value – Range: 0-1023 => -5.33V - +5.33V
- CV Offset – Range: 0-4096 => -5.33V - +5.33V
- Select User Sequence – Only active in user mode. Returns to User Sequence mode from parameter entry mode.
- Select Parameter – x means a single digit in the range of 0-n, where n = the number of parameters for a chosen function minus 1.
- Enter Parameter – xxxx means up to 4 digits depending on the parameter. The range also depends on the parameter. List items may be chosen, with 0 selecting 1st item.
- Disable Displays (Z) is used to speed up web-based scripting. Restore Displays by using the command ‘z’. These commands affect both the OLED display and the remote terminal.
- Display On (J1) and Display Off (J0) just affect the OLED display. Turning off the OLED display noticeably speeds up response when using the terminal interface.
- Inserting and deleting chars only work when entering strings.

## Settings

The Settings function displays information about the Spankulator as well as allowing some adjustments to various system parameters. Refer to the table below.

Parameter | Min | Max | Default
Version | -- | -- | Displays version#
CV Pot | Off | Value | Off
Sig In | Off | Value | Off
Quantize | No | Yes | No
Clock | Internal | External | Internal
Encoder Type | Normal | Reverse | Normal
WiFi | Enabled | Disabled | Enabled
Screen Saver | 1 | 9999 | 15
Reset | -- | -- | Push Trigger
Calibrate | -- | -- | Push Trigger

Notes:

1. Version shows the software version number. This is useful when communicating about bugs and questions.
2. CV Pot and Sig In functions affect the CV Out signal. They can be set to the following:
  a. Off - Disconnected
  b. Scale – Range: 0-100%
  c. Offset – Range: -5.33V - +5.33V
  d. Value – Range: -5.33V - +5.33V. Only active when the module is idle (NOT triggered).
  e. Note: Parameters altered by CV Pot and Sig In will remain altered after the setting has been changed until they are altered by another action.
3. Doubling Up - When CV Pot and Sig In are set the same, special rules apply:
  a. Scale – Signal is pre-scaled by Sig In, then scaled again by CV Pot.
  b. Offset – Signal is offset by Sig In, then offset again by CV Pot.
  c. Value – Signal is Sig In + CV Pot.
4. Clock can be set to External. In this case pulse lengths are irrelevant, but the levels at CV Out will be the same as they would in Internal mode. Feed the External Clock signal into Trig In.
5. Encoder Type takes the two types of rotary encoder into account. This makes them easier to purchase if one type is unavailable. If your Adjust knob is working opposite as it should, this is the setting that corrects it.
6. WiFi can be disabled here if you want to turn it off but retain your password.
7. Screen Saver prolongs the life of the OLED display. The screen will blank after the set number of minutes. Press any button to bring the display back.
8. Reset brings the Spankulator’s parameters back to their factory defaults. Note that WiFi parameters are unaffected.
9. Calibrate is a factory-only setting. Do not use.

## Software Update

When a software update becomes available, it will be posted on the website as a zipped package. The package contains 3 files. Unzip these into an empty folder on your machine.

1. Bossac.exe
2. Spankulator.ino.bin
3. Update.bat

These files work for the Windows OS. Mac and Linux users must install the GUI version of bossac and use that instead. Bossa can be found at: https://www.shumatech.com/web/products/bossa

Follow these steps to update the code. This procedure ensures that your rack won’t be inadvertently powered by the USB +5 volt supply.

1. Note: If the update changes the EEPROM storage mapping, the unit will automatically initiate a Software Reset. Any stored settings will be lost, so make sure to save these settings before updating if they are important.
2. Turn off power to the rack and remove the Spankulator.
3. Leaving the power cable connected, place the Spankulator on a non-conductive surface. Make sure nothing touches the Spankulator that might cause a short.
4. Re-power the rack and plug micro-USB cable into the Spankulator.
5. Run update.bat. It will show available COM ports. Choose by entering the number of the port.
6. If it connects properly, you will see a bunch of text being printed to the screen. This can generally be ignored. If the update succeeds, the Spankulator will reboot as normal with the new software installed. You should see the new version number in the greet screen.

## Crash Recovery

When things go wrong, as they sometimes do, the Spankulator might become unresponsive. When this happens, the program must be reset. Usually recycling the power* will fix the problem, but occasionally things have gone so bad that the code must be reloaded.

Usually, following the above update process will work. But occasionally things might have gone so bad that a hardware reset must be performed. There is a reset button on the Arduino 33 IoT. Pressing this twice quickly will force the Arduino into bootloader mode. You will see the yellow LED pulsate to indicate when the Arduino is in bootloader mode. The update process should work at this time. Please contact Greenface Labs directly if this doesn’t work.

*Make sure to unplug the USB cable before removing power.

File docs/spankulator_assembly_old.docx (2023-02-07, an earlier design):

# Spankulator Assembly Instructions

The Spankulator uses components on both sides of the board as well as stacked components to maximize rack space. Because of this, the order of assembly is designed to avoid installing a component that covers the holes of another component. Also, the order is intended to add components like the push buttons near the end of the process so they will not risk being damaged by the hot iron.

Because of the density of the circuitry, a conical .8mm tip soldering iron is suggested.

Difficulty: beginner. Not recommended for first three builds.

1. Install 4 12mm stand-offs to the front panel using screws. Set this aside for later.
2. Install C16, RV2 and RV3 on back side of board.
  a. RV2 must be installed before IC socket for U1.
  b. Trim the leads to insure proper fit of socket U1.
  c. Use caution while soldering the rest of the components so as not to bump the trim pots with the hot iron.
3. Install U5, all resistors, capacitors (except C3 and C4), diodes (not LEDs) and transistors on top side of board.
4. Install sockets U1, U2, U3 and U6.
5. Install connector J9.
6. Install 2 10mm display stand-offs with nuts.
7. Install 7mm FRAM standoff (p/n: 732-13045-ND) with screw on back of board.
8. Install J8 on back of board.
9. Fully insert FRAM header into J8. Use pliers to gently snug plastic down until it is flush with J8.
10. Install FRAM onto header and standoff. Solder and trim pins.
11. Solder header to Display board. Set this aside for later.
  a. Trim pins on top of display to insure proper fit onto the front panel.
  b. Note: the display is very fragile. Avoid unnecessary handling.
12. Install J2, J7, U4, RV3 and the two 15 pin sockets of A1 on back of board.
  a. heat sink side of U4 matches white line on board
13. Install C3 and C4
14. Install ICs into sockets.
15. Install display. Use wooden, round toothpicks to align display on standoffs. Insert toothpick from top and trim flush with display surface. (No standoffs were available that matched hole size on the display)
16. Loosely place the rest of the components (these should all be the ones that go through holes in the front panel) and attach front panel with the 4 nuts.
17. This should properly align all the front-panel components. Solder them in place.
18. Install Arduino on the back side of the board.
19. Attach knobs
20. That’s all! You’re ready to test.

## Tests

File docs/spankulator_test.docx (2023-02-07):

# Spankulator Test/Calibration Instructions

These instructions assume that the Spankulator program has already been loaded onto the Arduino. The Exp connector is tested when the Du Dad is installed.

You will need the following equipment:

1. DVM: .1% accuracy
2. Power supply: +/-12V connected to Eurorack power cable
3. Pulse generator: 5V pulses (could just be a push button)
4. Micro-USB cable
5. Terminal program (PuTTY is recommended)
6. DC voltage source: 1mV resolution for calibration
7. Pot tweaker (or small flat blade screwdriver) for calibration

Test procedure:

1. Set power supply for 25mA max current on +/-12 Volt rails
2. Connect power to unit under test
3. Check display to see normal boot sequence
4. Measure 3.3V +/- .05V at TP3
5. Test all buttons. Confirm that Yellow LED works.
6. Go to Up function, then connect USB
7. Test Rotary Encoder by adjusting a parameter. Encoder type may need to be set in Settings.
8. Test Activate button by pressing Rotary Encoder. Red LED goes ON indicating trigger is active.
9. Send 5V pulses into Trig In to confirm external trigger functions properly
10. Using Terminal program, send G0↲ to unit
11. Measure Low (<.5V) at Trig Out, Green LED is OFF
12. Send G1↲ to unit
13. Measure High (>4.5V) at Trig Out, Green LED is ON
14. Using Terminal program, send T0↲ to unit
15. Measure Low (<.5V) at Tog Out, Blue LED is OFF
16. Send T1↲ to unit
17. Measure High (>4.5V) at Tog Out, Blue LED is ON
18. Using Terminal program, send c0↲ to unit
19. Measure <-5V at CV Out
20. Send c1023↲ to unit
21. Measure >5V at CV Out
22. Send P3↲ to unit
23. Test CV Pot by measuring voltage at CV Out. Voltage range: approx. -5.3V to +5.3V
24. Remove current limit from supply
25. Go to Settings and calibrate the ADC and DAC
26. Confirm that WiFi works
27. That’s all! You’re ready to rock and roll.

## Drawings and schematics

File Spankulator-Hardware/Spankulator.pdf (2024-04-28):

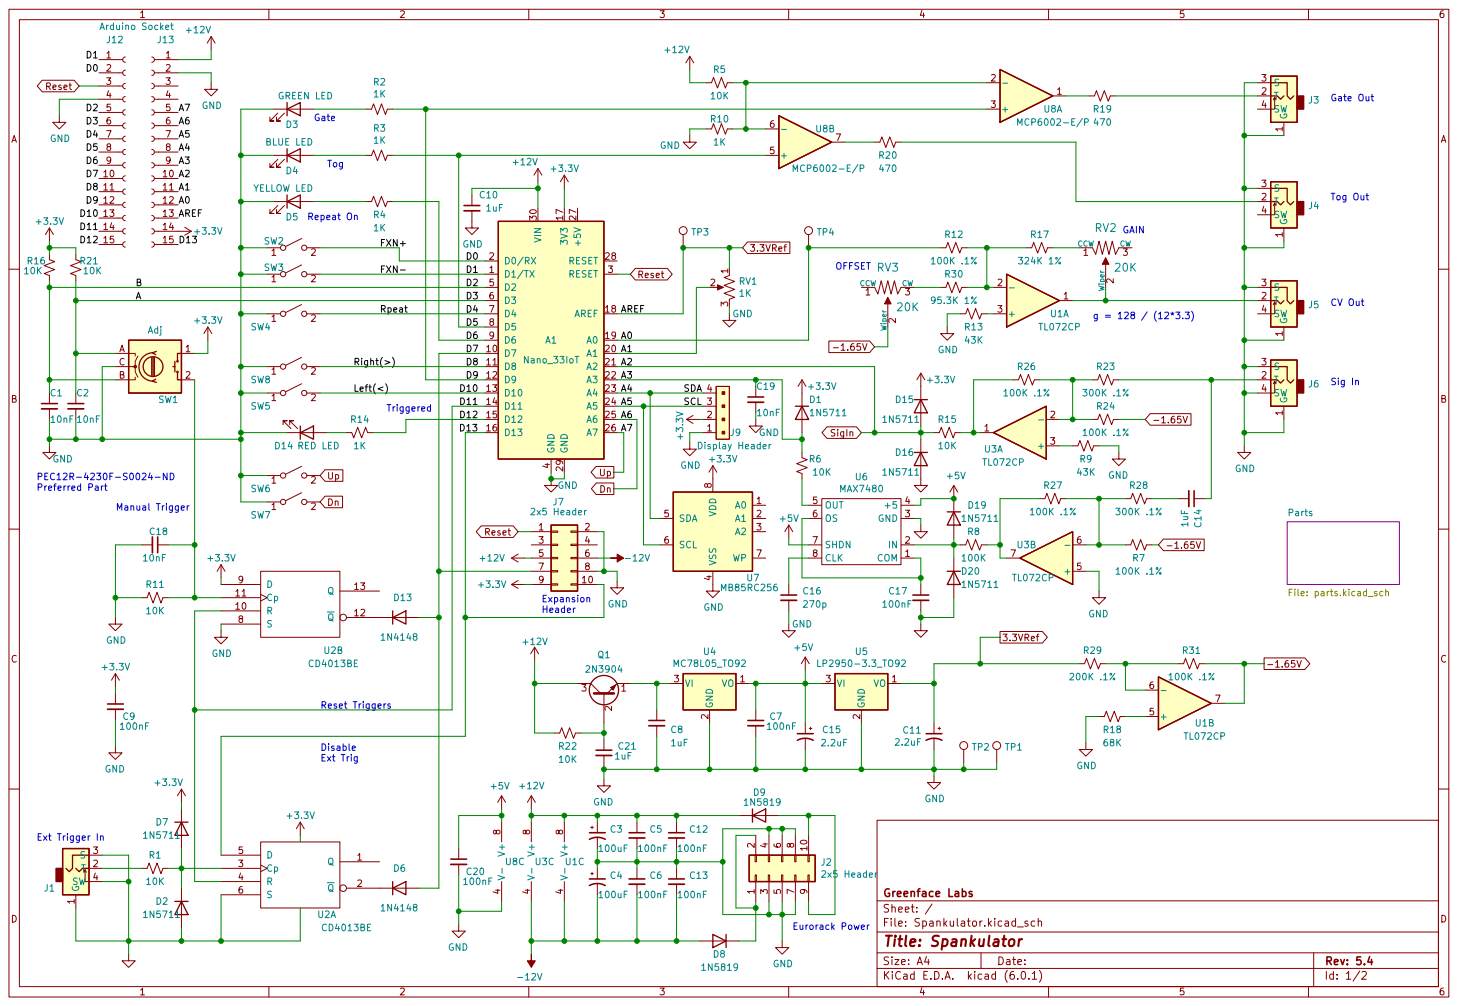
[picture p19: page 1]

4 SDA 5 SCL 6 WP 7 VDD

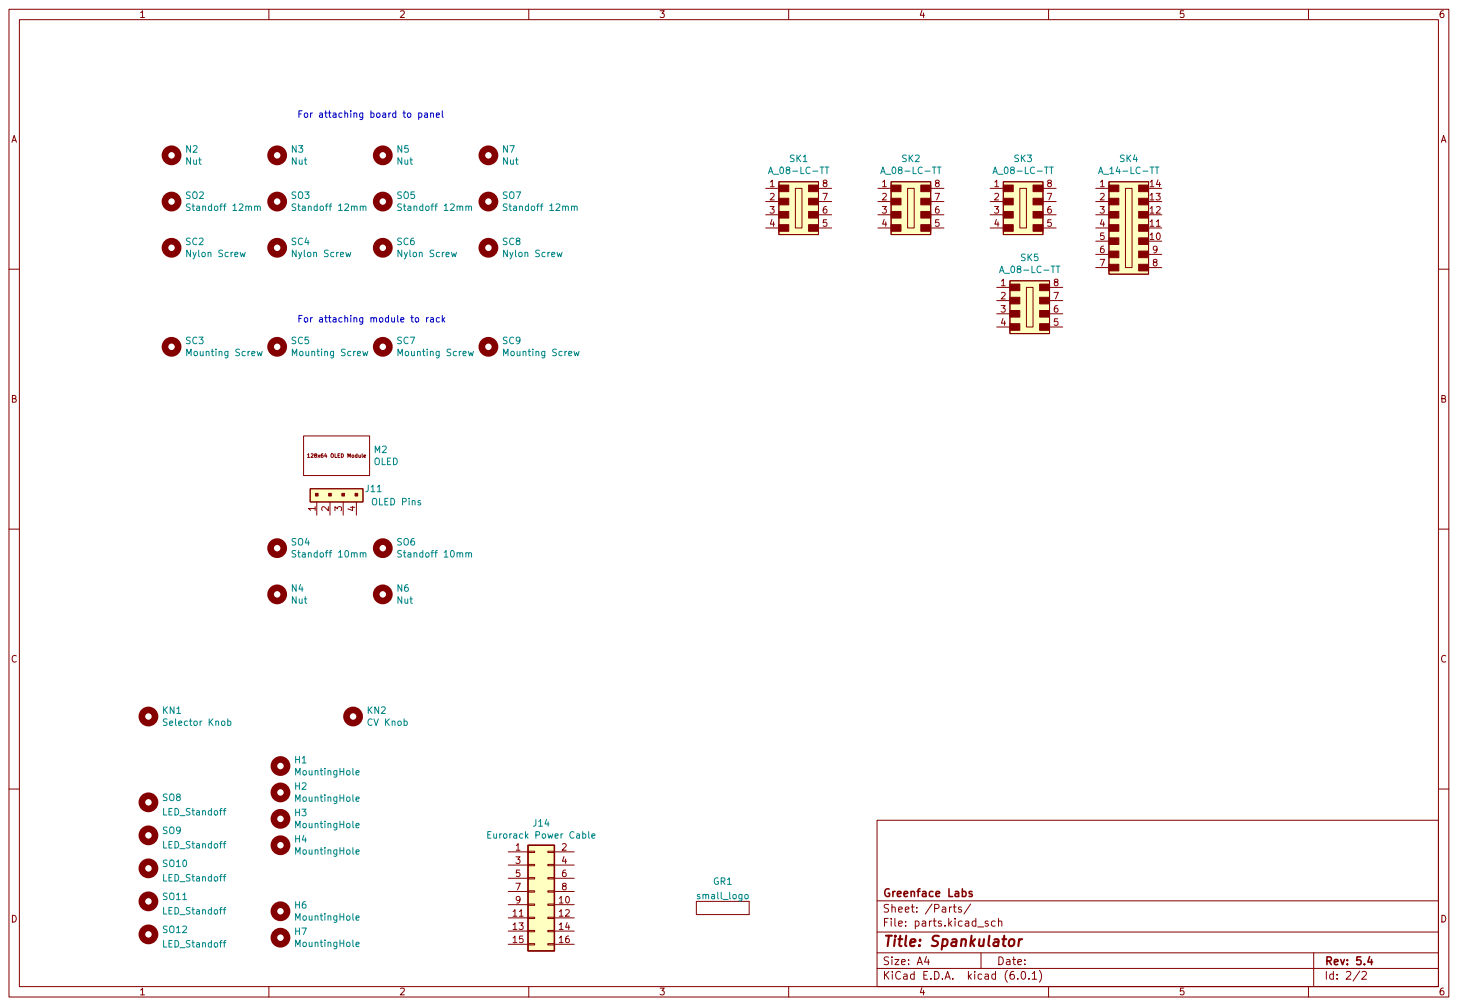
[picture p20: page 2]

For attaching board to panel

For attaching module to rack

File: parts.kicad_sch Sheet: /Parts/ Greenface Labs

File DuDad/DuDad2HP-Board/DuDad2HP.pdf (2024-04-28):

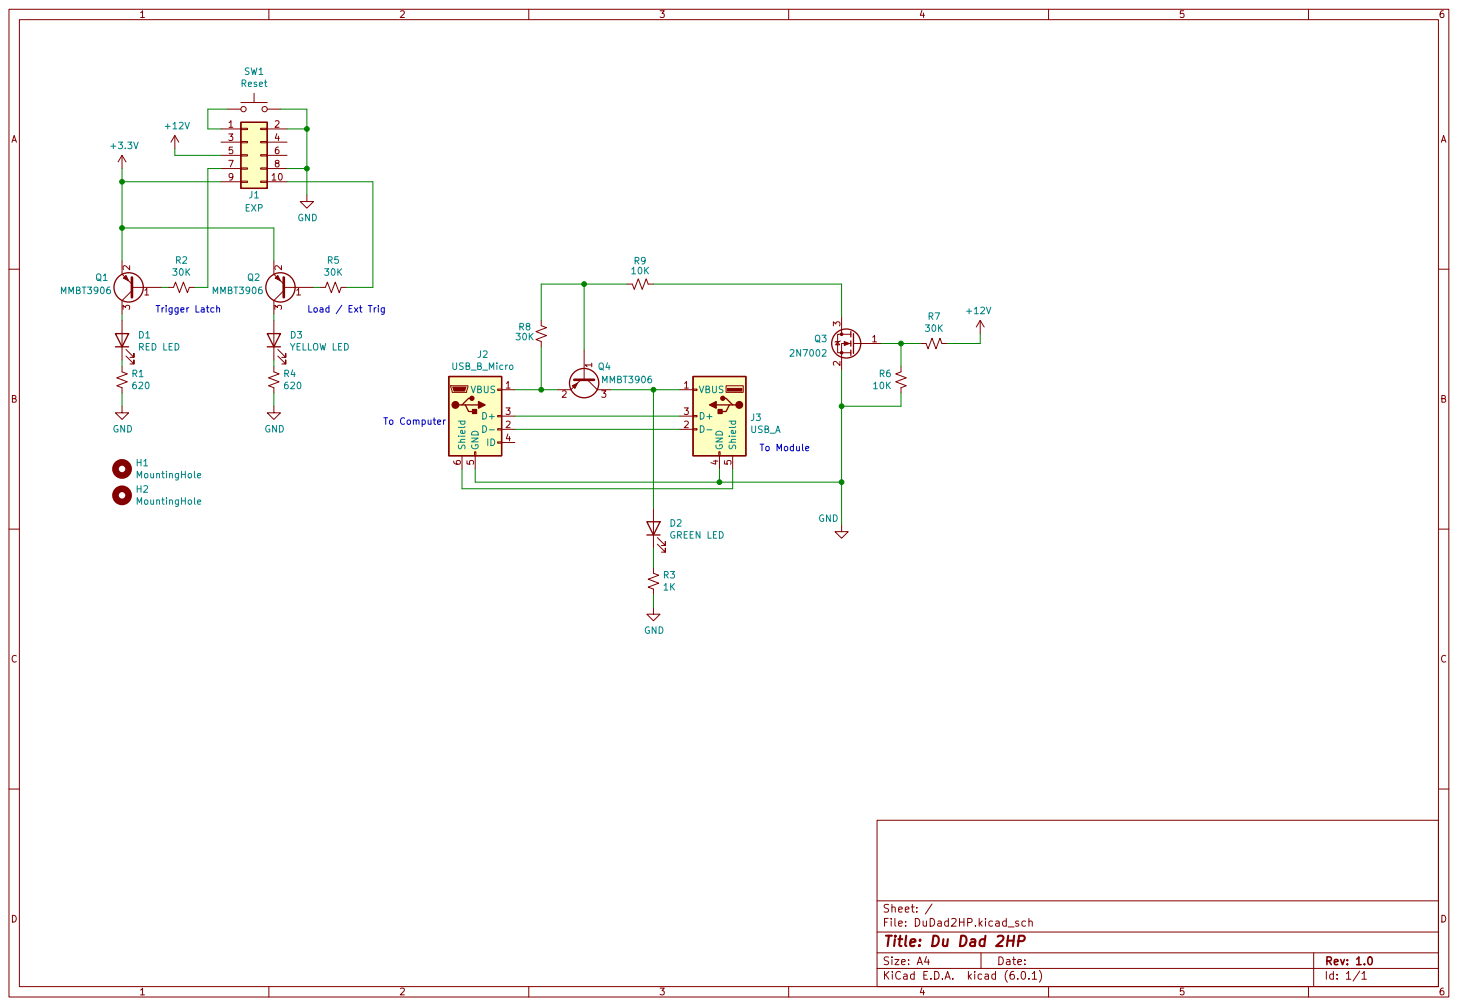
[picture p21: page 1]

File: DuDad2HP.kicad_sch Sheet: /
Id: 1/1 Title: Du Dad 2HP

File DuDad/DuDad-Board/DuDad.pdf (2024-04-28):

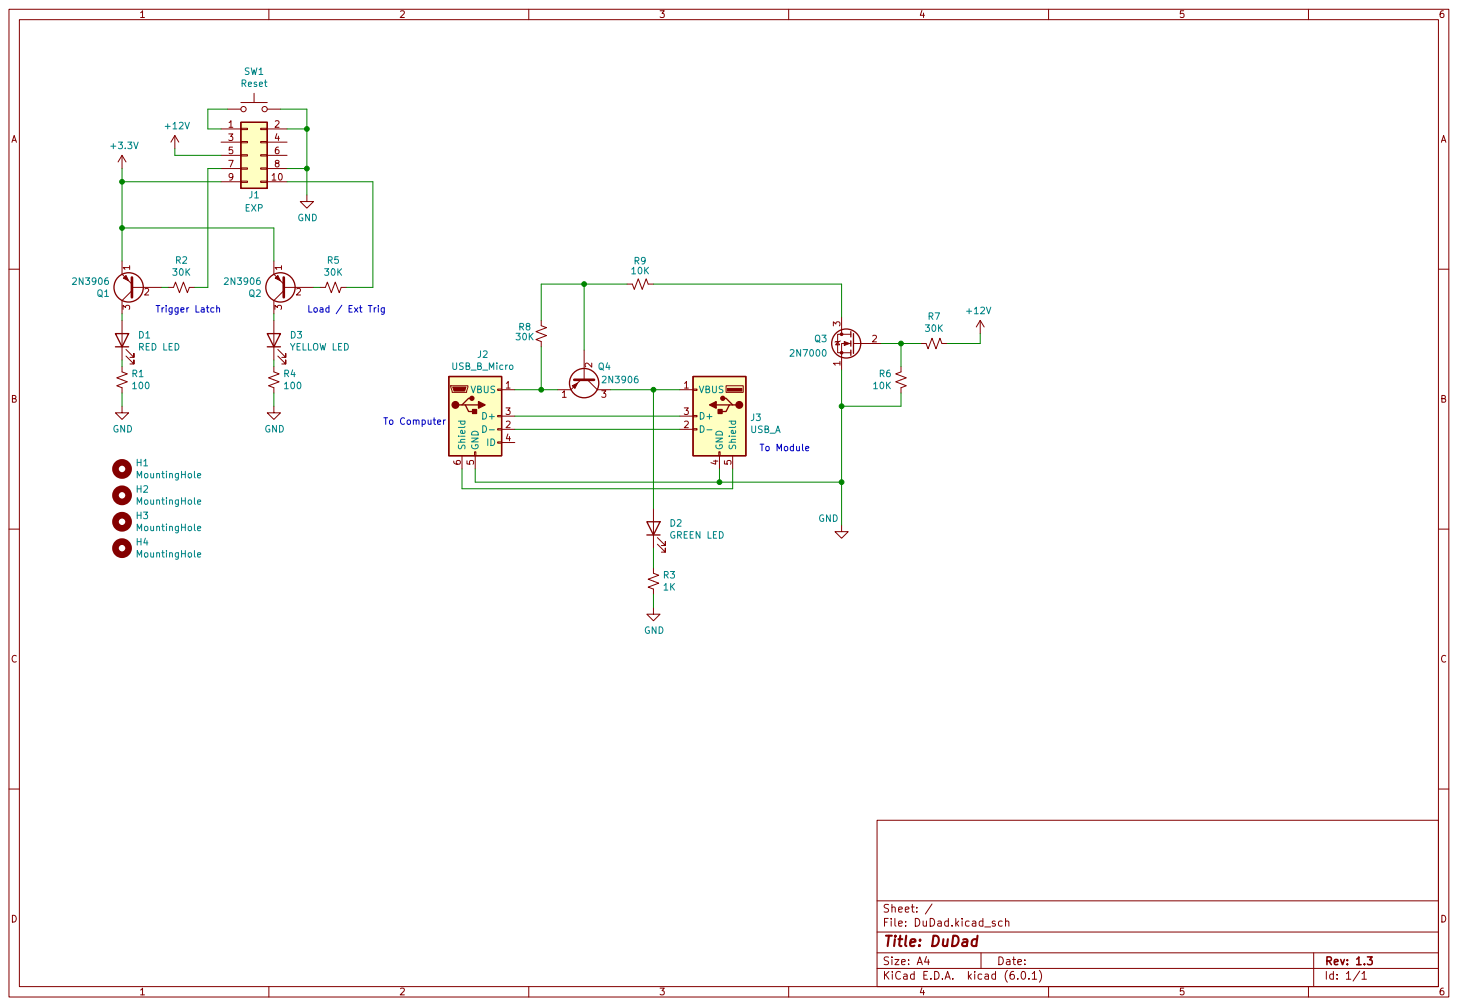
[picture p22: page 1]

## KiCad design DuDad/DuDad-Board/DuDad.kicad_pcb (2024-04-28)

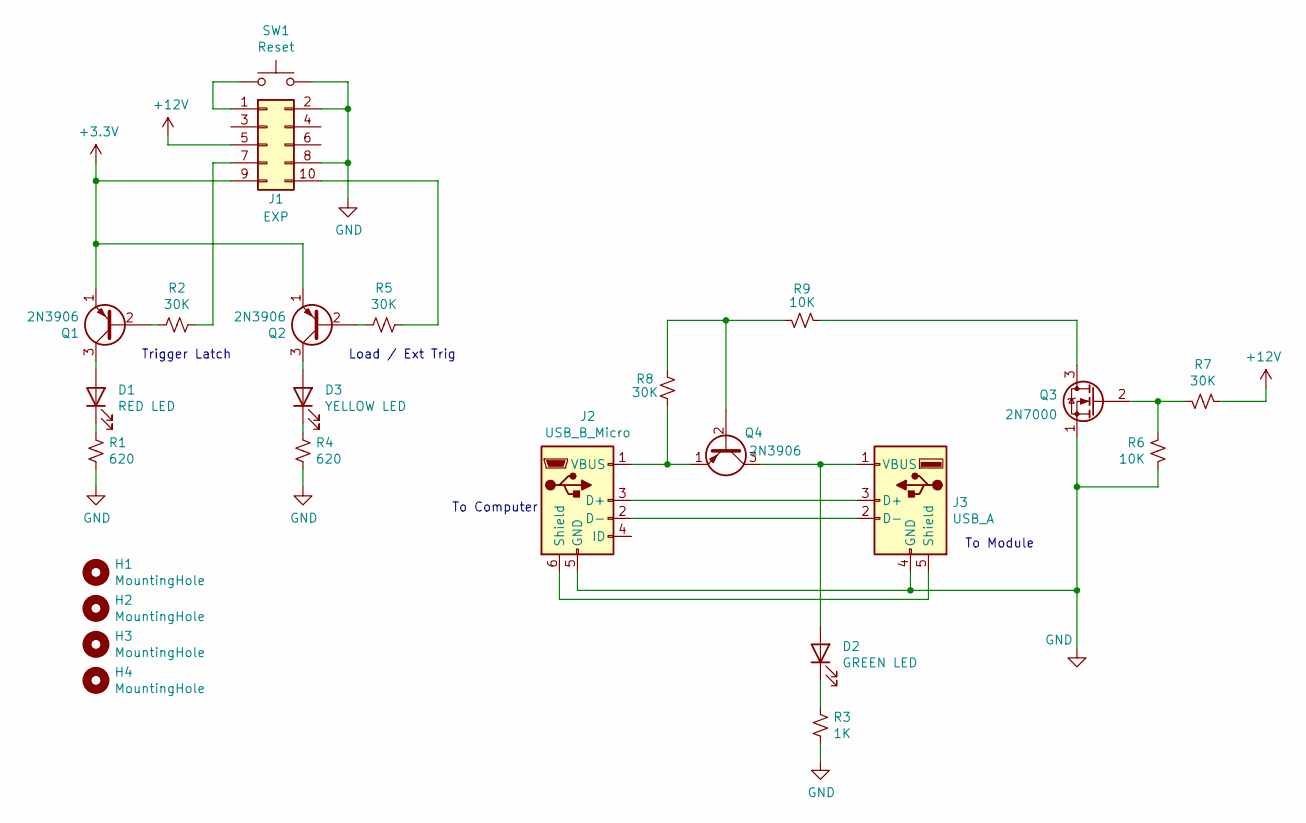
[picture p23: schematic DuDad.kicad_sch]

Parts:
D1: RED LED; LED_D3.0mm; Digi-Key Part 732-5005-ND
D2: GREEN LED; LED_D3.0mm; Digi-Key Part 732-5008-ND
D3: YELLOW LED; LED_D3.0mm; Digi-Key Part 732-5010-ND
H1, H2, H3, H4: MountingHole; MountingHole_2.5mm
J1: EXP; PinHeader_2x05_P2.54mm_Vertical; Digi-Key Part S2011EC-05-ND
J2: USB_B_Micro; USB_Micro-B_Wuerth_614105150721_Vertical; Digi-Key Part 2073-USB3131-30-0230-ACT-ND
J3: USB_A; USB_A_Amphenol_UE27AE54100_Vertical; Digi-Key Part UE27AE54100-ND
Q1, Q2, Q4: 2N3906; TO-92_Inline_Wide; Digi-Key Part 2N3906TFCT-ND
Q3: 2N7000; TO-92_Inline_Wide; Digi-Key Part 2N7000FS-ND
R1, R4: 620; R_Axial_DIN0207_L6.3mm_D2.5mm_P10.16mm_Horizontal; Digi-Key Part CF14JT620RCT-ND
R2, R5, R7, R8: 30K; R_Axial_DIN0207_L6.3mm_D2.5mm_P10.16mm_Horizontal; Digi-Key Part CF14JT30K0CT-ND
R3: 1K; R_Axial_DIN0207_L6.3mm_D2.5mm_P10.16mm_Horizontal; Digi-Key Part CF14JT1K00CT-ND
R6, R9: 10K; R_Axial_DIN0207_L6.3mm_D2.5mm_P10.16mm_Horizontal; Digi-Key Part CF14JT10K0CT-ND
SW1: Reset; SW_PUSH_6mm; Digi-Key Part 450-1653-ND

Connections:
+3V3: J1.9, Q1.1 (E), Q2.1 (E)
+12V: J1.5, R7.2
GND: J1.2, J1.8, J2.5 (GND), J3.4 (GND), Q3.1 (S), R1.1, R3.1, R4.1, R6.1, SW1.2
unnamed: D1.1 (K), R1.2
unnamed: D1.2 (A), Q1.3 (C)
unnamed: D2.1 (K), R3.2
unnamed: D2.2 (A), J3.1 (VBUS), Q4.3 (C)
unnamed: D3.1 (K), R4.2
unnamed: D3.2 (A), Q2.3 (C)
unnamed: J1.1, SW1.1
unnamed: J1.7, R2.1
unnamed: J1.10, R5.1
unnamed: J2.1 (VBUS), Q4.1 (E), R8.2
unnamed: J2.2 (D-), J3.2 (D-)
unnamed: J2.3 (D+), J3.3 (D+)
unnamed: J2.6 (Shield), J3.5 (Shield)
unnamed: Q1.2 (B), R2.2
unnamed: Q2.2 (B), R5.2
unnamed: Q3.2 (G), R6.2, R7.1
unnamed: Q3.3 (D), R9.1
unnamed: Q4.2 (B), R8.1, R9.2

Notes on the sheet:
To Computer
Trigger Latch
To Module
Load / Ext Trig

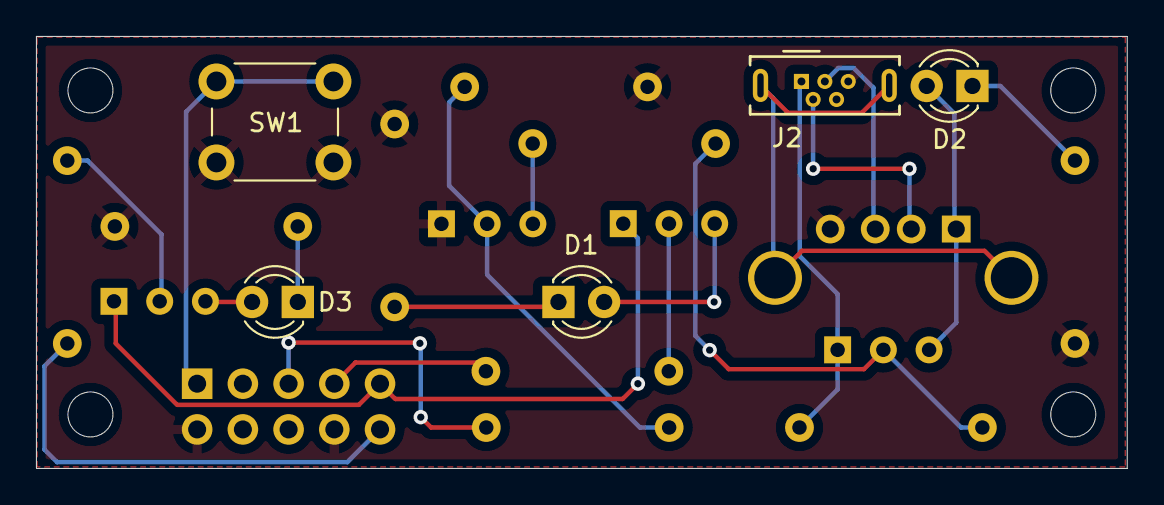
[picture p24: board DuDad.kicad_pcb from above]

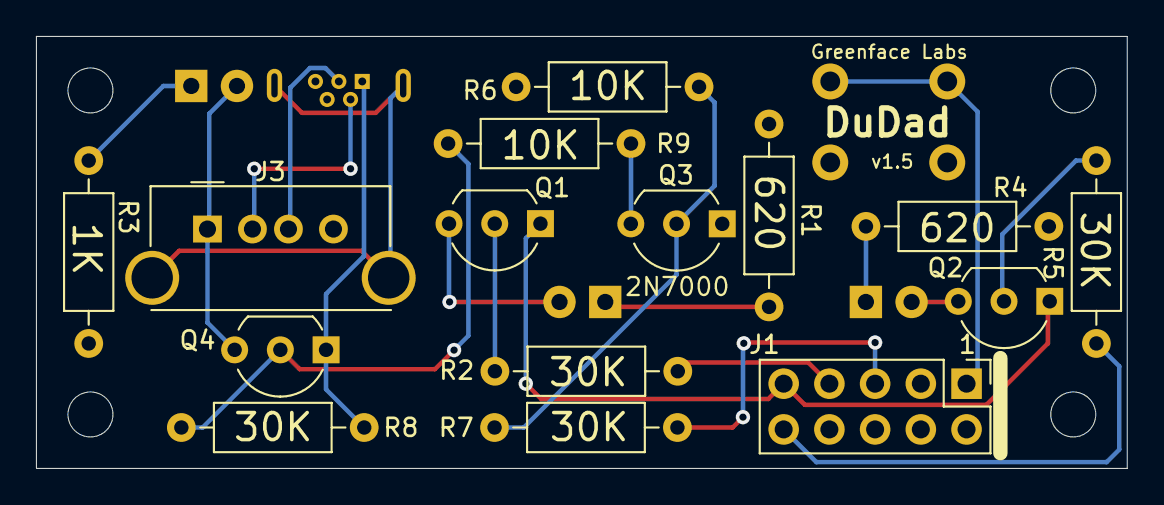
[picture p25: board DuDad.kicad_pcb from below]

Board: 2 copper layers, 60.6 x 24.0 mm, 24 parts (15 on the bottom side), 21 nets.

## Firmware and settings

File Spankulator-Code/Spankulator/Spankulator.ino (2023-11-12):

// Spankulator main
typedef void (*FunctionPointer)();

// Load 3rd party libraries
#include <stdlib.h>
#include <Wire.h> // For I2C comm, but needed for not getting compile error
#include <Timer5.h>
#include <Adafruit_FRAM_I2C.h>
#include <WiFiNINA.h>
#include "secrets/secrets/arduino_secrets.h"

#define BOARD_GENERATION 5
#include "version_num.h"
#include "hardware_defs.h"

void adc_config_hardware();

// settings functions
int settings_get_board_generation();
uint16_t settings_get_pot_fxn();
uint16_t settings_get_dc_fxn();
boolean settings_is_quantized();
String settings_get_device_name();
boolean settings_is_ext_clk();
uint16_t settings_get_ext_trig();
void settings_put_ext_trig(uint16_t);
void settings_put_quantized(uint16_t);
void set_encoder();
bool wifi_enabled(void);
void send_status_to_USB();
void send_data_to_USB(char cmd);
uint16_t settings_get_wifi();

// hilevel functions
void set_repeat_on(bool val);
void reset_trigger();
bool trigger_go(unsigned long ms);
void new_fxn();
// void reset_inactivity_timer();
// void check_inactivity_timer();
void restore_display();
void check_keyboard();
void check_serial();
void check_display_restore();
String old_status = "";

// variables
String version_num = VERSION_NUM;
volatile int keypress = 0;               // set by several sources
volatile boolean fp_key_pressed = false; // only set by front panel keypress
volatile int inactivity_timer = 0;
boolean remote_adjusting = false;
boolean esc_mode = false;
boolean is_triggered = false;
boolean user_doing_trigger = false;
String in_str = ""; // for serial input
boolean cmd_available = false;
String wifi_ui_message = "";
int user_entering_param = 1;

uint16_t cv_val;
int adj; // from pot
int scale_adj = ADC_FS;
int offset_adj = ADC_MID;
float scale;
int offset;

// Load Greenface libraries
#include <TerminalVT100.h>
#include <RotaryEncoder.h>
#include <Greenface_EEPROM.h>
#include <EEPROM_fxns.h>
#include <Greenface_gadget.h>
#include <WIFI_Util.h>

#include "hardware_fxns.h"
#include "general_fxns.h"

#include "SPANK_ui.h"
#include "face1.h" // greenface logo art

Greenface_gadget *selected_fxn;
EEPROM_Int fxn = EEPROM_Int(0, 1000);  // set max to real max when num_fxns has been defined
EEPROM_Bool repeat_on = EEPROM_Bool(); // sizeof fxn val

#define UP_FXN 0
#define DN_FXN 1
#define STRETCH_FXN 2
#define TOGGLE_FXN 3
#define MAYTAG_FXN 4
#define LFO_FXN 5
#define USER_FXN 6
#define DVM_FXN 7
#define WIFI_FXN 8
#define SETTINGS_FXN 9

#include <Greenface_wifi_fxns.h>
#include "SPANK_Trigger.h"
SPANK_Trigger trigger_control;
FunctionPointer trigger_fxn;

#include "up_spanker.h"
#include "dn_spanker.h"
#include "stretch_spanker.h"
#include "toggle_spanker.h"
#include "maytag_spanker.h"

#include "lfo.h"
#include "user_fxn.h"
#include "adc.h"
#include "dac.h"
#include "dvm_fxn.h"
#include "wifi_ui.h"
#include "settings_fxn.h"
// #include "wdt.h"

#include "hilevel_fxns.h"

#define SETTINGS_INFO_LABEL_ROW "19"
#define SETTINGS_INFO_ROW "20"
void terminal_print_status()
{
  if (ui.terminal_mirror)
  {
    ui.t.setCursor(STATUS_ROW, "33");
    ui.t.print(is_triggered ? "TRIGGERED" : "         ");
    String rpeat = repeat_on.get() ? "ON " : "OFF";
    ui.t.setCursor(FXN_ROW, "16");
    ui.t.print("Repeat:" + rpeat);

    ui.t.setCursor(FXN_ROW, "28");
    float percent = 100 * scale;
    ui.t.print("Scale:" + String(percent) + String("%"));
    ui.t.clrToEOL();

    ui.t.setCursor(FXN_ROW, "42");
    float volts = (float(offset_adj) / ADC_FS) * 10.66 - 5.33;
    ui.t.print(" Offset:" + String(volts) + String("V"));
    ui.t.clrToEOL();

    // ui.t.setCursor(FXN_ROW, "55");
    // ui.t.print(" Clk:" + String(settings_is_ext_clk() ? "EXT" : "INT"));
    // ui.t.clrToEOL();

    ui.t.setCursor(SETTINGS_INFO_LABEL_ROW, "1");
    ui.t.print(F("Settings Info"));
    ui.t.clrToEOL();

    ui.t.setCursor(SETTINGS_INFO_ROW, "1");
    ui.t.print("Pot:" + settings_spanker.get_param_as_string(SETTINGS_POT_FXN));
    ui.t.clrToEOL();

    ui.t.setCursor(SETTINGS_INFO_ROW, "12");
    ui.t.print("SigIn:" + settings_spanker.get_param_as_string(SETTINGS_DC_FXN));
    ui.t.clrToEOL();

    ui.t.setCursor(SETTINGS_INFO_ROW, "24");
    ui.t.print(" Clk:" + settings_spanker.get_param_as_string(SETTINGS_CLK));
    ui.t.clrToEOL();

    ui.t.setCursor(SETTINGS_INFO_ROW, "37");
    ui.t.print(" TrigIn:" + settings_spanker.get_param_as_string(SETTINGS_EXT_TRIG));
    ui.t.clrToEOL();

    ui.t.setCursor(SETTINGS_INFO_ROW, "53");
    ui.t.print(" Quantize:" + settings_spanker.get_param_as_string(SETTINGS_QUANTIZE));
    ui.t.clrToEOL();

    ui.t.setCursor(DEBUG_ROW, "1");
  }
}

// EEO must come after last EEPROM var is declared
#define EEO Greenface_EEPROM::eeprom_offset

bool trig_memory;
void setup(void)
{
  begin_all();
  ee_info.begin(false);
  ee_info.xfer();
  delay(500);

  offset_adj = ADC_MID;
  do_cv_mod();
  scale = 1.0;
  offset = 0;

  set_encoder(); // sets msb,lsb for two types of encoder

  if (!eeprom_is_initialized() || !digitalRead(up_button_pin))
  {
    init_all();
    wifi_password.init();
    wifi_password.put("");
    wifi_ssid.init();
    wifi_ssid.put("");
  }

  trigger_fxn = noop;
  enable_triggers();

  // connect if wifi is active
  wifi_attempt_connect(false);

  ui.splash();
  delay(2500);
  exe_fxn();
  trig_memory = !is_triggered; // force terminal_print_status()
  heartbeat_begin();           // must come after exe_fxn()
}

void loop()
{
  char cmd;
  static bool gate_memory = false;
  static bool tog_memory = false;
  // ui.terminal_debug("inactivity_timer: " + String(inactivity_timer) + " keypress: " + String(keypress));

  // check_serial affects
  // instr and cmd_avail for process_cmd
  // and keypress used directly below
  check_keyboard();
  // Serial.println("Keyboard checked!");

  check_serial();
  // Serial.println("Serial checked!");

  static int ms_save;

  if (is_usb_direct() && !is_dvm())
  {
    ms_save = millis();
    if (gate.get() != gate_memory)
    {
      gate_memory = gate.get();
      send_status_to_USB();
    }

    if (tog.get() != tog_memory)
    {
      tog_memory = tog.get();
      send_status_to_USB();
    }

    if (is_triggered != trig_memory)
    {
      trig_memory = is_triggered;
      terminal_print_status();
      send_status_to_USB();
    }
  }

  if (keypress || cmd_available)
  {
    if (cmd_available)
    {
      cmd = in_str[0];
      process_cmd(in_str);
      in_str = "";
      cmd_available = false;
    }
    else
    {
      cmd = keypress;
      check_display_restore();
      process_keypress();
    }
    if (usb_direct_enabled())
    {
      // ui.t.println("Howdy!");
      cmd = (cmd == '\n') ? ' ' : cmd;
      send_data_to_USB(cmd);
    }
  }
  else
  {
    if (fxn.get() != DVM_FXN)
    {
      do_cv_mod(); // dvm does this in trigger fxn
    }
    // Serial.println("cv mod checked!");
    housekeep();
    do_server();
  }

  check_trigger();
  check_rotary_encoder();
  ui.check_inactivity_timer(settings_get_inactivity_timeout());
  // Serial.println("Whew!");
}

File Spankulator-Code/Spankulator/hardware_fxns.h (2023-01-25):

// hardware
#include <BufferedOutput.h>
const byte toggle_out_pin = 5;
const byte repeat_led_pin = 6;
const byte gate_out_pin = 9;
const byte disable_trigger_pin = 11;
const byte triggered_led_pin = 12;
const byte disable_ext_trigger_pin = 13;

const byte aout_pin = A0;
// const byte ain1_pin = A1;
// const byte ain2_pin = A2;
// const byte ain3_pin = A3;

// buttons
const byte up_button_pin = 0; // fxn +
const byte dn_button_pin = 1; // fxn -
const byte repeat_button_pin = 4;
const byte trigger_button_pin = 7;
const byte param_up_button_pin = A7; // ^
const byte param_dn_button_pin = A6; // v
const byte left_button_pin = 10;     // <
const byte right_button_pin = 8;     // >

BufferedOutput gate(gate_out_pin);
BufferedOutput tog(toggle_out_pin);

// adc
typedef enum _adc_chan
{
    ADC_POT = A1,
    ADC_DC = A2,
    ADC_AC = A3,
} adc_chan;

int readADC(adc_chan chan)
{
    if (chan == ADC_POT)
    {
        return analogRead(chan);
    }
    else
    {
        return ADC_FS - analogRead(chan);
    }
}

float read_dc_filtered(adc_chan chan)
{
    float xn;
    float yn;
    static float xn1;
    static float yn1;
    int raw = readADC(chan);
    // int dac_raw = DAC_FS - (raw >> 2);
    // scale_and_offset(&dac_raw);
    // analog_out(dac_raw);
    xn = (ADC_MID - raw);
    yn = 0.969 * yn1 + 0.0155 * xn + 0.0155 * xn1;
    // yn = (xn + xn1) / 2;
    xn1 = xn;
    yn1 = yn;
    return yn + ADC_MID;
}

// Rotary Encoder
void intFxnA(void)
{
    e.aChanInt();
}

void intFxnB(void)
{
    e.bChanInt();
}

// DAC
// #define DAC_CTRLB_REFSEL_Pos _UINT8_(6)                                                           /* (DAC_CTRLB) Reference Selection Position */
// #define DAC_CTRLB_REFSEL_Msk (_UINT8_(0x3) << DAC_CTRLB_REFSEL_Pos)                               /* (DAC_CTRLB) Reference Selection Mask */
// #define DAC_CTRLB_REFSEL(value) (DAC_CTRLB_REFSEL_Msk & (_UINT8_(value) << DAC_CTRLB_REFSEL_Pos)) /* Assigment of value for REFSEL in the DAC_CTRLB register */
// #define DAC_CTRLB_REFSEL_INT1V_Val _UINT8_(0x0)                                                   /* (DAC_CTRLB) Internal 1.0V reference  */
// #define DAC_CTRLB_REFSEL_AVCC_Val _UINT8_(0x1)                                                    /* (DAC_CTRLB) AVCC  */
// #define DAC_CTRLB_REFSEL_VREFP_Val _UINT8_(0x2)                                                   /* (DAC_CTRLB) External reference  */
// #define DAC_CTRLB_REFSEL_INT1V (DAC_CTRLB_REFSEL_INT1V_Val << DAC_CTRLB_REFSEL_Pos)               /* (DAC_CTRLB) Internal 1.0V reference Position  */
// #define DAC_CTRLB_REFSEL_AVCC (DAC_CTRLB_REFSEL_AVCC_Val << DAC_CTRLB_REFSEL_Pos)                 /* (DAC_CTRLB) AVCC Position  */
// #define DAC_CTRLB_REFSEL_VREFP (DAC_CTRLB_REFSEL_VREFP_Val << DAC_CTRLB_REFSEL_Pos)               /* (DAC_CTRLB) External reference Position  */

void hardware_begin()
{
    pinMode(repeat_led_pin, OUTPUT);
    pinMode(disable_trigger_pin, OUTPUT);
    pinMode(disable_ext_trigger_pin, OUTPUT);
    pinMode(triggered_led_pin, OUTPUT);
    pinMode(0, INPUT);
    pinMode(1, INPUT);
    pinMode(A1, INPUT);
    pinMode(A2, INPUT);
    pinMode(A3, INPUT);

    pinMode(up_button_pin, INPUT_PULLUP);
    pinMode(dn_button_pin, INPUT_PULLUP);
    pinMode(repeat_button_pin, INPUT_PULLUP);
    pinMode(trigger_button_pin, INPUT_PULLUP);
    pinMode(param_up_button_pin, INPUT_PULLUP);
    pinMode(param_dn_button_pin, INPUT_PULLUP);
    pinMode(right_button_pin, INPUT_PULLUP);
    pinMode(left_button_pin, INPUT_PULLUP);

    // adc_config_hardware();

    pinMode(param_dn_button_pin, INPUT_PULLUP);

    // analogReadCorrection(-23, 2000);
    // analogReadCorrection(-30, 2047);

    // DAC_CTRLB_REFSEL(DAC_CTRLB_REFSEL_INT1V_Val);
    analogWriteResolution(10);
    // DAC->CTRLB.reg &= 0x3f; // use EXT as the reference
    // DAC->CTRLB.reg |= 0x80; // use EXT as the reference
    analogWrite(A0, 511);
}

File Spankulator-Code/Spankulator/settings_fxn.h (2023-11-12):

enum
{
  SETTINGS_VER = 0,
  SETTINGS_POT_FXN,
  SETTINGS_DC_FXN,
  SETTINGS_QUANTIZE,
  SETTINGS_CLK,
  SETTINGS_EXT_TRIG,
  SETTINGS_ENCODER,
  SETTINGS_WIFI,
  SETTINGS_USB_DIRECT,
  SETTINGS_SCREEN,
  SETTINGS_NAME,
  SETTINGS_RESET,
  SETTINGS_CAL,
  SETTINGS_BOARD_GENERATION,
  SETTINGS_NUM_PARAMS,
};

enum
{
  SETTING_CV_OFF = 0,
  SETTING_CV_SCALE,
  SETTING_CV_OFFSET,
  SETTING_CV_VALUE,
};

uint16_t _settings_params[SETTINGS_NUM_PARAMS];
uint16_t _settings_mins[] = {0, SETTING_CV_OFF, SETTING_CV_OFF, 0, 0, 0, 0, 0, 0, 1, 0, 0, 0, 1};
uint16_t _settings_maxs[] = {0, SETTING_CV_VALUE, SETTING_CV_VALUE, 1, 1, 1, 1, 2, 1, 9999, 0, 0, 1, BOARD_GENERATION};
uint16_t _settings_init_vals[] = {0, SETTING_CV_OFF, SETTING_CV_OFF, 1, 0, 0, 0, 1, 0, 15, 0, 0, 0, BOARD_GENERATION};
uint16_t *settings_stuff[] = {_settings_params, _settings_mins, _settings_maxs, _settings_init_vals};
String settings_labels[] = {"Version: ", "CV Pot: ", "Sig In: ", "Quantize: ", "Clock: ", "Ext Trig: ", "Encoder Type: ", "WiFi: ", "USB Direct: ", "Screen Saver: ", "Name: ", "Reset: ", "Calibrate: ", "Board Generation: "};
String settings_string_params[] = {VERSION_NUM, "Off,Scale ,Offset,Value ", "Off,Scale ,Offset,Value ", "No ,Yes", "Internal,External", "Enabled ,Disabled", "Normal ,Reverse", "Disabled,Enabled ,Reset", "Disabled,Enabled ", "", "$~", "Push Activate", "ADC,DAC", ""};
EEPROM_String settings_device_name(20);
EEPROM_String settings_string_vars[] = {settings_device_name};
Greenface_gadget settings_spanker("Settings", settings_labels, settings_stuff, sizeof(_settings_params) / sizeof(_settings_params[0]));
bool settings_param_active[] = {0, 0, 0, 0, 0, 0, 0, 0, 0, 0, 0, 1, 1, 0};

void settings_fxn()
{
  adc_cal_screen = 0;
  dac_cal_screen = 0;
  selected_fxn = &settings_spanker;
  settings_spanker.display();
  disable_ext_trigger();
  trigger_fxn = noop;
  trigger_control.triggered = false;
}

bool is_usb_direct()
{
  return settings_spanker.get_param(SETTINGS_USB_DIRECT) ? true : false;
}

void set_usb_direct()
{
  ui.terminal_mirror = !is_usb_direct();
}

void settings_put_usb_direct(int val)
{
  settings_spanker.param_put(val, SETTINGS_USB_DIRECT);
  set_usb_direct();
}

uint16_t settings_get_pot_fxn()
{
  return settings_spanker.get_param(SETTINGS_POT_FXN);
}

uint16_t settings_get_dc_fxn()
{
  return settings_spanker.get_param(SETTINGS_DC_FXN);
}

boolean settings_is_quantized()
{
  return settings_spanker.get_param(SETTINGS_QUANTIZE) == 1;
}

void settings_put_quantized(uint16_t val)
{
  // settings_spanker.put_param_num(SETTINGS_QUANTIZE);
  settings_spanker.param_put(val, SETTINGS_QUANTIZE);
}

String settings_get_device_name()
{
  return settings_spanker.get_param_as_string_var(SETTINGS_NAME);
}

boolean settings_is_ext_clk()
{
  return settings_spanker.get_param(SETTINGS_CLK) == 1;
}

void settings_put_ext_clk(uint16_t val)
{
  // settings_spanker.put_param_num(SETTINGS_CLK);
  settings_spanker.param_put(val, SETTINGS_CLK);
  if (settings_is_ext_clk())
  {
    set_repeat_on(false);
  }
  // set_repeat_on(!settings_is_ext_clk());
}

void settings_toggle_ext_clk()
{
  settings_spanker.put_param_num(SETTINGS_CLK);
  settings_spanker.put_param(settings_is_ext_clk() ? 0 : 1);
  set_repeat_on(!settings_is_ext_clk());
}

uint16_t settings_get_ext_trig()
{
  return settings_spanker.get_param(SETTINGS_EXT_TRIG);
}

void settings_put_ext_trig(uint16_t val)
{
  // settings_spanker.put_param_num(SETTINGS_EXT_TRIG);
  settings_spanker.param_put(val, SETTINGS_EXT_TRIG);
  put_disable_ext_trigger(val);
}

void settings_toggle_ext_trig()
{
  settings_put_ext_trig(!settings_get_ext_trig());
}

void settings_set_ext_trig()
{
  int ext_trig = settings_spanker.get_param(SETTINGS_EXT_TRIG);
  put_disable_ext_trigger(ext_trig);
}

uint16_t settings_get_encoder_type()
{
  return settings_spanker.get_param(SETTINGS_ENCODER);
}

bool wifi_enabled()
{
  return settings_spanker.get_param(SETTINGS_WIFI);
}

uint16_t settings_get_wifi()
{
  return settings_spanker.get_param(SETTINGS_WIFI);
}

bool usb_direct_enabled()
{
  return settings_spanker.get_param(SETTINGS_USB_DIRECT);
}

int settings_get_inactivity_timeout()
{
  return settings_spanker.get_param(SETTINGS_SCREEN);
}

int settings_get_board_generation()
{
  return settings_spanker.get_param(SETTINGS_BOARD_GENERATION);
}

void settings_put_param(int val)
{
  settings_spanker.put_param(val);
  switch (settings_spanker.param_num)
  {
  case SETTINGS_ENCODER:
    set_encoder();
    break;
  case SETTINGS_SCREEN:
    restore_display();
    break;
  case SETTINGS_USB_DIRECT:
    set_usb_direct();
    break;
  case SETTINGS_WIFI:
    // mode = settings_fxn.get_param(SETTINGS_WIFI);
    // if (settings_spanker.get_param(SETTINGS_WIFI) == 2)
    // {
    //   select_wifi_screen = 0;
    //   // system_message = "WiFi Reset";
    // }
    break;
  }
}
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

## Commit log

2022-09-26 Release 1.0
    Full package.
    [Spankulator-B_Cu.gbr, Spankulator-B_Mask.gbr, Spankulator-B_Paste.gbr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]
2022-10-11 Adds power on reset
    [Spankulator.ino]
2022-10-22 Adds DuDad. Updates Excel to use Power Query.
    [DuDad-B_Cu.gbr, DuDad-B_Mask.gbr, DuDad-B_Paste.gbr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]
2022-10-22 Updates ReadMe
    [SpankulatorPanel.kicad_pcb]
2022-10-24 Updates readme and DuDad board.
    [DuDad-B_Cu.gbr, DuDad-B_Mask.gbr, DuDad-B_Paste.gbr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]
2022-10-24 Updates readme, moves docs to docs folder
    [DuDad.csv, DuDad.kicad_sch]
2022-10-26 Adds 2HP DuDad
    [DuDad-B_Cu.gbr, DuDad-B_Mask.gbr, DuDad-B_Paste.gbr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]
2022-11-02 Consolidates zip_gerbers.bat. Improves BOM files.
    [DuDad2HP-B_Cu.gbr, DuDad2HP-B_Mask.gbr, DuDad2HP-B_Paste.gbr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]
2022-11-08 Adds Arduino headers to lcsc bom
    [Spankulator.kicad_sch, spankulator_bom.xlsx, spankulator_split_bom.xlsx]
2022-11-26 v4.4 of Spankulator Board
    Many changes to BOM generation. Adds Python scripts.
    [Spankulator-B_Cu.gbr, Spankulator-B_Mask.gbr, Spankulator-B_Paste.gbr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]
2022-12-02 Updates hardware to v5.0
    [Spankulator-B_Cu.gbr, Spankulator-B_Mask.gbr, Spankulator-B_Paste.gbr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]
2022-12-02 Finish update to 5.0
    [Spankulator.kicad_sch, parts.kicad_sch]
2023-01-05 Adds CV control from Sig Input
    Rename ADC inputs
    Create dedicated read function
    Adds CV control from Sig Input
2023-01-05 Fixes to User function
    Doesn't crash web app when user sequence is empty.
    Fixes String entry to user sequence
    Adds P and V commands for CV control. (leftover from previous commit)
    [hilevel_fxns.h]
2023-01-10 Update hilevel_fxns.h
    Adds switch to DAC external ref as debug. Not used in code.
2023-01-10 Update Spankulator.pdf
    Updates DAC circuitry. Rev 5.1
2023-01-11 Upgrade board to 5.1
    Changes to DAC output components.
    Improvements to silkscreen.
    [Spankulator-B_Cu.gbr, Spankulator-B_Mask.gbr, Spankulator-B_Paste.gbr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]
2023-01-25 Corrects 3904 part number
    [Spankulator.kicad_sch, spankulator_bom.csv]
2023-01-25 New interrupt structure
    Also improves terminal_print_status()
2023-01-26 Fixes parts too close
    Fixes gain pot bumping into Exp connector.
    Moves all TPs to board top
    More components lay flat now
    Adds Argh Ptoo face to silkscreen
    [Spankulator-B_Cu.gbr, Spankulator-B_Mask.gbr, Spankulator-B_Paste.gbr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]
2023-01-28 Replaces FET outputs with OP Amp.
    [Spankulator-B_Cu.gbr, Spankulator-B_Mask.gbr, Spankulator-B_Paste.gbr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]
2023-01-28 Replaces FET output with OP Amp
2023-01-28 Adds socket for OP Amp
    [Spankulator.kicad_sch, parts.kicad_sch, spankulator_bom.csv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]
2023-02-04 Adds debounce to Repeat button
2023-02-06 Fixes to calibrate functions
    [adc.h]
2023-02-07 Updates assembly doc. Adds old version and test doc.
2023-02-08 Doesn't try to change Scale, Offset, Value when these are controlled elsewhere.
    [hardware_defs.h, hilevel_fxns.h, settings_fxn.h]
2023-06-10 Adds insert and remove char to user mode.
2023-07-06 Fixes to External Clock mode
    [Spankulator.ino, hilevel_fxns.h, settings_fxn.h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]
2023-07-18 Adds Board Generation in settings
    Allows correct sensing of reset triggers signal.
    [Spankulator.ino, general_fxns.h, settings_fxn.h]
2023-07-18 Uses correct knob for CV Adj
    [parts.kicad_sch, spankulator_bom.csv, spankulator_full.csv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]
2023-07-18 Swaps * and & remote commands
    [hilevel_fxns.h]
2023-07-20 Fixes Repeat button action.
    [hilevel_fxns.h]
2023-10-05 Version 5.3 of the board
    Updated reverse protection diode
    [Spankulator-B_Cu.gbr, Spankulator-B_Mask.gbr, Spankulator-B_Paste.gbr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]
2023-10-05 Moves TP1 to bottom side
    [Spankulator-B_Cu.gbr, Spankulator-B_Mask.gbr, Spankulator-B_Paste.gbr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]
2023-10-05 Changes panel color to black
    [SpankulatorPanel.kicad_pcb]
2023-10-06 Fixes display in user mode when in app and triggered
    [Spankulator.ino, hilevel_fxns.h]
2023-10-06 Removes output resistor. Adjusts RC in reference filter
    [Spankulator.kicad_sch, spankulator_bom.csv, spankulator_full.csv]
2023-10-10 Removes output resistor.
2023-10-16 New panel, new board.
    [Spankulator-B_Cu.gbr, Spankulator-B_Mask.gbr, Spankulator-B_Paste.gbr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]
2023-10-18 Fixes cmd/zip_gerbers.
    Now it includes edge cuts layer when making front panel
    [Spankulator-B_Cu.gbr, Spankulator-B_Mask.gbr, Spankulator-B_Paste.gbr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]
2023-10-21 Fixes user entering param bug
    Adds is_usb_direct. Fixes bug where status is sent when not in usb direct mode.
    [Spankulator.ino, hilevel_fxns.h, settings_fxn.h]
2023-11-05 Fixes bad math when offset gets large.
    [general_fxns.h]
2023-11-12 Fixes to WiFi reset
    Sets WiFi enabled when resetting.
    [hilevel_fxns.h]
2023-11-12 Need to explicitly spec arduino_secrets.h
    For Mac Arduino IDE compile
2023-11-12 Adds WiFi reset and settings_get_wifi()
    Leaves commented out code just in case. Checking this next.
    [settings_fxn.h]
2023-11-12 Adds settings_get_wifi()
    Also inits user_entering_param. Fixes bugs with param controls in app.
    [Spankulator.ino]
2023-12-05 Uses arduino-cli for updater. Adds updater.sh
2023-12-06 Uses arduino-cli for make and loading
2024-04-28 Ups resistor values to dim LEDs. Adds generate BOMs.
    [DuDad-B_Cu.gbr, DuDad-B_Mask.gbr, DuDad-B_Paste.gbr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]
2024-04-28 Adds pullup resistors to rotary encoder.
    [Spankulator.kicad_sch, parts.kicad_sch]
